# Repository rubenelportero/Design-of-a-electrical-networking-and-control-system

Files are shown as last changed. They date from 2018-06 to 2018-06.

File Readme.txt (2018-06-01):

Rubén García Segovia - 2018
https://github.com/rubenelportero

Este trabajo está bajo la licencia Creative Commons
de atribución y compartir igual 4.0. Todo el contenido
se encuentra bajo esta licencia, excepto las hojas
de características de los componentes electrónicos,
las cuales tienen sus licencias propietarias propias.
https://creativecommons.org/licenses/by-sa/4.0/legalcode

Además, todos los programas y códigos adjuntados en este proyecto 
son software libre: Puedes redistribuirlos o modificarlos
bajo los términos y condiciones de la licencia general de GNU
en su versión 3 o superior. 
http://www.gnu.org/licenses/

----------------------------------------------------------------------

This work is licensed under the Creative Commons
Attribution share-alike 4.0 license. All the content
is under this license, except for the included electronic
component data sheets, which have their own license. 
To view a copy of this license:
https://creativecommons.org/licenses/by-sa/4.0/legalcode

All programs/codes attached in this project are free software: 
you can redistribute them and/or modify them under the terms of 
the GNU General Public License as published by the Free Software 
Foundation, either version 3 of the License, or any later version.

All programs/codes are distributed in the hope that they will be useful,
but WITHOUT ANY WARRANTY; without even the implied warranty of
MERCHANTABILITY or FITNESS FOR A PARTICULAR PURPOSE.  See the
GNU General Public License for more details.

You should have received a copy of the GNU General Public License
along with this program.  If not, see <http://www.gnu.org/licenses/>.

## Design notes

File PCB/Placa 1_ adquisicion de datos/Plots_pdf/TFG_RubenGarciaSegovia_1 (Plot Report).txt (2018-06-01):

Plot Report
-----------

Report Written:     Monday, May 21, 2018
Project Path:       C:\Users\rubenelportero\Desktop\TFG\CD\PCB\Placa 1_ adquisicion de datos\TFG_RubenGarciaSegovia.prj
Design Path:        C:\Users\rubenelportero\Desktop\TFG\CD\PCB\Placa 1_ adquisicion de datos\TFG_RubenGarciaSegovia_1.pcb
Design Title:       
Created:            25/04/2018 18:19:07
Last Saved:         21/05/2018 18:58:55
Editing Time:       38 min
Units:              thou (precision 0)

Device Settings
===============

Gerber Settings
===============

    Leading zero suppression.
    G01 assumed throughout.
    Line termination <*> <CR> <LF>.
    3.5 format absolute inches.

    Format commands defined in Gerber file.
    Aperture table defined in Gerber file.
    Hardware arcs allowed.

Drill Settings
==============

    Excellon Format 1    Format 3.5 absolute in inches.
    Leading zero suppression.

Plots Output
============

Gerber Output
=============

C:\Users\rubenelportero\Desktop\TFG\CD\PCB\Placa 1_ adquisicion de datos\Plots_pdf\TFG_RubenGarciaSegovia_1 - Top Documentation.gbr

    Layers:
    ---------------------
    Top Documentation

    D-Code Shape  (thou)
    -----------------------
    D17    Round 5.00
    D18    Round 1.97

Gerber Output
=============

C:\Users\rubenelportero\Desktop\TFG\CD\PCB\Placa 1_ adquisicion de datos\Plots_pdf\TFG_RubenGarciaSegovia_1 - Top Silkscreen.gbr

    Layers:
    ------------------
    Top Silkscreen

    D-Code Shape  (thou)
    -----------------------
    D17    Round 5.00
    D19    Round 7.87

Gerber Output
=============

C:\Users\rubenelportero\Desktop\TFG\CD\PCB\Placa 1_ adquisicion de datos\Plots_pdf\TFG_RubenGarciaSegovia_1 - Top Copper.gbr

    Layers:
    --------------
    Top Copper

    D-Code Shape  (thou)
    ------------------------------------
    D71    Square 76.77
    D20    Round 76.77
    D23    Round 60.00
    D27    Round 15.00
    D28    Round 48.00
    D78    Square 64.96
    D79    Round 64.96
    D117   Rectangle 590.55 X 1102.36
    D118   Round 50.00

Gerber Output
=============

C:\Users\rubenelportero\Desktop\TFG\CD\PCB\Placa 1_ adquisicion de datos\Plots_pdf\TFG_RubenGarciaSegovia_1 - Top Solder Mask.gbr

    Layers:
    -------------------
    Top Solder Mask

    D-Code Shape  (thou)
    ------------------------------------
    D89    Round 66.00
    D90    Square 82.77
    D91    Round 82.77
    D94    Square 70.96
    D95    Round 70.96
    D103   Round 54.00
    D119   Rectangle 596.55 X 1108.36

Gerber Output
=============

C:\Users\rubenelportero\Desktop\TFG\CD\PCB\Placa 1_ adquisicion de datos\Plots_pdf\TFG_RubenGarciaSegovia_1 - Top Paste Mask.gbr

    Layers:
    ------------------
    Top Paste Mask

    D-Code Shape  (thou)
    ------------------------------------
    D120   Rectangle 584.55 X 1096.36

Gerber Output
=============

C:\Users\rubenelportero\Desktop\TFG\CD\PCB\Placa 1_ adquisicion de datos\Plots_pdf\TFG_RubenGarciaSegovia_1 - Bottom Copper.gbr

    Layers:
    -----------------
    Bottom Copper

    D-Code Shape  (thou)
    -----------------------
    D16    Round 100.00
    D71    Square 76.77
    D20    Round 76.77
    D23    Round 60.00
    D27    Round 15.00
    D28    Round 48.00
    D78    Square 64.96
    D79    Round 64.96
    D118   Round 50.00
    D121   Round 25.00
    D122   Round 35.00

Gerber Output
=============

C:\Users\rubenelportero\Desktop\TFG\CD\PCB\Placa 1_ adquisicion de datos\Plots_pdf\TFG_RubenGarciaSegovia_1 - Bottom Copper (Resist).gbr

    Layers:
    -----------------
    Bottom Copper

    D-Code Shape  (thou)
    -----------------------
    D10    Square 86.77
    D11    Round 86.77
    D12    Round 70.00
    D112   Square 74.96
    D113   Round 74.96

Gerber Output
=============

C:\Users\rubenelportero\Desktop\TFG\CD\PCB\Placa 1_ adquisicion de datos\Plots_pdf\TFG_RubenGarciaSegovia_1 - Bottom Copper (Paste).gbr

    Layers:
    -----------------
    Bottom Copper

    D-Code Shape  (thou)
    -----------------------

NC Drill Output
===============

C:\Users\rubenelportero\Desktop\TFG\CD\PCB\Placa 1_ adquisicion de datos\Plots_pdf\TFG_RubenGarciaSegovia_1 - Drill Data - [Through Hole].drl

    Output:
    ---------------------------
    Plated Round Drill Holes
    Plated Slots
    Plated Board Outlines

    Tool  Size           Count   ID
    --------------------------------------
    T001  0.02400 inches 17    D
    T002  0.03200 inches 32    A
    T003  0.04331 inches 20    B
    T004  0.05118 inches 12    C
    --------------------------------------
    Total                81
    --------------------------------------

C:\Users\rubenelportero\Desktop\TFG\CD\PCB\Placa 1_ adquisicion de datos\Plots_pdf\TFG_RubenGarciaSegovia_1 - Drill Data - [Through Hole] (Unplated).drl

    Output:
    -----------------------------
    Unplated Round Drill Holes
    Unplated Slots
    Unplated Board Outlines

    Tool  Size           Count   ID
    --------------------------------------
    T001  0.02500 inches 1
    --------------------------------------
    Total                1
    --------------------------------------

Gerber Output
=============

C:\Users\rubenelportero\Desktop\TFG\CD\PCB\Placa 1_ adquisicion de datos\Plots_pdf\TFG_RubenGarciaSegovia_1 - Drill Ident Drawing - [Through Hole].gbr

    Layers:
    ------------------
    [Through Hole]

Drill Ident Drawing
===================

    Drill Plated Size Shape ID
    -----------------------------------
    32    Y      100  Round A
    43    Y      100  Round B
    51    Y      100  Round C
    24    Y      100  Round D

    D-Code Shape  (thou)
    -----------------------
    D16    Round 100.00
    D17    Round 5.00

End Of Report.

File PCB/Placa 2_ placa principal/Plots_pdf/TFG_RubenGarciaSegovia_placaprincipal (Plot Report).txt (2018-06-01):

Plot Report
-----------

Report Written:     Monday, May 21, 2018
Project Path:       C:\Users\rubenelportero\Desktop\TFG\CD\PCB\Placa 2_ placa principal\TFG_RubenGarciaSegovia_placaprincipal.prj
Design Path:        C:\Users\rubenelportero\Desktop\TFG\CD\PCB\Placa 2_ placa principal\TFG_RubenGarciaSegovia_placaprincipal.pcb
Design Title:       
Created:            14/05/2018 12:30:43
Last Saved:         21/05/2018 18:56:52
Editing Time:       201 min
Units:              thou (precision 0)

Device Settings
===============

Gerber Settings
===============

    Leading zero suppression.
    G01 assumed throughout.
    Line termination <*> <CR> <LF>.
    3.5 format absolute inches.

    Format commands defined in Gerber file.
    Aperture table defined in Gerber file.
    Hardware arcs allowed.

Drill Settings
==============

    Excellon Format 1    Format 3.5 absolute in inches.
    Leading zero suppression.

Plots Output
============

Gerber Output
=============

C:\Users\rubenelportero\Desktop\TFG\CD\PCB\Placa 2_ placa principal\Plots_pdf\TFG_RubenGarciaSegovia_placaprincipal - Top Documentation.gbr

    Layers:
    ---------------------
    Top Documentation

    D-Code Shape  (thou)
    -----------------------
    D18    Round 1.97

Gerber Output
=============

C:\Users\rubenelportero\Desktop\TFG\CD\PCB\Placa 2_ placa principal\Plots_pdf\TFG_RubenGarciaSegovia_placaprincipal - Top Silkscreen.gbr

    Layers:
    ------------------
    Top Silkscreen

    D-Code Shape  (thou)
    -----------------------
    D17    Round 5.00
    D19    Round 7.87
    D70    Round 10.00
    D73    Round 6.00

Gerber Output
=============

C:\Users\rubenelportero\Desktop\TFG\CD\PCB\Placa 2_ placa principal\Plots_pdf\TFG_RubenGarciaSegovia_placaprincipal - Top Copper.gbr

    Layers:
    --------------
    Top Copper

    D-Code Shape  (thou)
    ----------------------------------------------
    D17    Round 5.00
    D70    Round 10.00
    D71    Square 76.77
    D20    Round 76.77
    D22    Rectangle 55.00 X 60.00
    D23    Round 60.00
    D27    Round 15.00
    D28    Round 48.00
    D74    Rectangle 11.00 X 58.00  Rotation 90
    D75    Rectangle 11.00 X 58.00
    D76    Square 47.24
    D77    Round 47.24
    D78    Square 64.96
    D79    Round 64.96
    D80    Square 46.61
    D81    Round 46.61
    D82    Rectangle 25.59 X 70.87
    D83    Round 44.49
    D84    Rectangle 55.00 X 60.00  Rotation 90
    D85    Rectangle 19.69 X 29.53  Rotation 90
    D86    Round 56.00

Gerber Output
=============

C:\Users\rubenelportero\Desktop\TFG\CD\PCB\Placa 2_ placa principal\Plots_pdf\TFG_RubenGarciaSegovia_placaprincipal - Top Solder Mask.gbr

    Layers:
    -------------------
    Top Solder Mask

    D-Code Shape  (thou)
    ----------------------------------------------
    D87    Rectangle 17.00 X 64.00  Rotation 90
    D88    Rectangle 17.00 X 64.00
    D89    Round 66.00
    D90    Square 82.77
    D91    Round 82.77
    D92    Square 53.24
    D93    Round 53.24
    D94    Square 70.96
    D95    Round 70.96
    D96    Square 52.61
    D97    Round 52.61
    D98    Rectangle 31.59 X 76.87
    D99    Round 50.49
    D100   Rectangle 61.00 X 66.00  Rotation 90
    D101   Rectangle 61.00 X 66.00
    D102   Rectangle 25.69 X 35.53  Rotation 90
    D103   Round 54.00
    D104   Round 62.00

Gerber Output
=============

C:\Users\rubenelportero\Desktop\TFG\CD\PCB\Placa 2_ placa principal\Plots_pdf\TFG_RubenGarciaSegovia_placaprincipal - Top Paste Mask.gbr

    Layers:
    ------------------
    Top Paste Mask

    D-Code Shape  (thou)
    ----------------------------------------------
    D72    Rectangle 49.00 X 54.00
    D105   Rectangle 5.00 X 52.00  Rotation 90
    D106   Rectangle 5.00 X 52.00
    D107   Rectangle 19.59 X 64.87
    D108   Rectangle 49.00 X 54.00  Rotation 90
    D109   Rectangle 13.69 X 23.53  Rotation 90

Gerber Output
=============

C:\Users\rubenelportero\Desktop\TFG\CD\PCB\Placa 2_ placa principal\Plots_pdf\TFG_RubenGarciaSegovia_placaprincipal - Bottom Copper.gbr

    Layers:
    -----------------
    Bottom Copper

    D-Code Shape  (thou)
    -----------------------
    D17    Round 5.00
    D70    Round 10.00
    D71    Square 76.77
    D20    Round 76.77
    D23    Round 60.00
    D27    Round 15.00
    D28    Round 48.00
    D76    Square 47.24
    D77    Round 47.24
    D78    Square 64.96
    D79    Round 64.96
    D80    Square 46.61
    D81    Round 46.61
    D83    Round 44.49
    D86    Round 56.00

Gerber Output
=============

C:\Users\rubenelportero\Desktop\TFG\CD\PCB\Placa 2_ placa principal\Plots_pdf\TFG_RubenGarciaSegovia_placaprincipal - Bottom Copper (Resist).gbr

    Layers:
    -----------------
    Bottom Copper

    D-Code Shape  (thou)
    -----------------------
    D10    Square 86.77
    D11    Round 86.77
    D12    Round 70.00
    D110   Square 57.24
    D111   Round 57.24
    D112   Square 74.96
    D113   Round 74.96
    D114   Square 56.61
    D115   Round 56.61
    D116   Round 54.49

Gerber Output
=============

C:\Users\rubenelportero\Desktop\TFG\CD\PCB\Placa 2_ placa principal\Plots_pdf\TFG_RubenGarciaSegovia_placaprincipal - Bottom Copper (Paste).gbr

    Layers:
    -----------------
    Bottom Copper

    D-Code Shape  (thou)
    -----------------------

NC Drill Output
===============

C:\Users\rubenelportero\Desktop\TFG\CD\PCB\Placa 2_ placa principal\Plots_pdf\TFG_RubenGarciaSegovia_placaprincipal - Drill Data - [Through Hole].drl

    Output:
    ---------------------------
    Plated Round Drill Holes
    Plated Slots
    Plated Board Outlines

    Tool  Size           Count   ID
    --------------------------------------
    T001  0.02400 inches 106   G
    T002  0.02480 inches 4     F
    T003  0.03087 inches 14    E
    T004  0.03150 inches 28    C
    T005  0.03200 inches 49    A
    T006  0.04331 inches 36    D
    T007  0.05118 inches 4     B
    --------------------------------------
    Total                241
    --------------------------------------

C:\Users\rubenelportero\Desktop\TFG\CD\PCB\Placa 2_ placa principal\Plots_pdf\TFG_RubenGarciaSegovia_placaprincipal - Drill Data - [Through Hole] (Unplated).drl

    Output:
    -----------------------------
    Unplated Round Drill Holes
    Unplated Slots
    Unplated Board Outlines

    Tool  Size           Count   ID
    --------------------------------------
    T001  0.02500 inches 1
    --------------------------------------
    Total                1
    --------------------------------------

Gerber Output
=============

C:\Users\rubenelportero\Desktop\TFG\CD\PCB\Placa 2_ placa principal\Plots_pdf\TFG_RubenGarciaSegovia_placaprincipal - Drill Ident Drawing - [Through Hole].gbr

    Layers:
    ------------------
    [Through Hole]

Drill Ident Drawing
===================

    Drill Plated Size Shape ID
    -----------------------------------
    32    Y      100  Round A
    51    Y      100  Round B
    31    Y      100  Round C
    43    Y      100  Round D
    31    Y      100  Round E
    25    Y      100  Round F
    24    Y      100  Round G

    D-Code Shape  (thou)
    -----------------------
    D16    Round 100.00
    D17    Round 5.00

End Of Report.

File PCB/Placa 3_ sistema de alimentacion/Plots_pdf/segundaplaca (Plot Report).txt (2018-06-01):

Plot Report
-----------

Report Written:     Monday, May 21, 2018
Project Path:       C:\Users\rubenelportero\Desktop\TFG\CD\PCB\Placa 3_ sistema de alimentacion\segundaplaca.prj
Design Path:        C:\Users\rubenelportero\Desktop\TFG\CD\PCB\Placa 3_ sistema de alimentacion\segundaplaca.pcb
Design Title:       
Created:            30/04/2018 19:52:52
Last Saved:         02/05/2018 17:16:53
Editing Time:       29 min
Units:              thou (precision 0)

Device Settings
===============

Gerber Settings
===============

    Leading zero suppression.
    G01 assumed throughout.
    Line termination <*> <CR> <LF>.
    3.5 format absolute inches.

    Format commands defined in Gerber file.
    Aperture table defined in Gerber file.
    Hardware arcs allowed.

Drill Settings
==============

    Excellon Format 1    Format 3.5 absolute in inches.
    Leading zero suppression.

Plots Output
============

Gerber Output
=============

C:\Users\rubenelportero\Desktop\TFG\CD\PCB\Placa 3_ sistema de alimentacion\Plots_pdf\segundaplaca - Top Documentation.gbr

    Layers:
    ---------------------
    Top Documentation

    D-Code Shape  (thou)
    -----------------------
    D18    Round 1.97

Gerber Output
=============

C:\Users\rubenelportero\Desktop\TFG\CD\PCB\Placa 3_ sistema de alimentacion\Plots_pdf\segundaplaca - Top Silkscreen.gbr

    Layers:
    ------------------
    Top Silkscreen

    D-Code Shape  (thou)
    -----------------------
    D17    Round 5.00
    D19    Round 7.87
    D70    Round 10.00

Gerber Output
=============

C:\Users\rubenelportero\Desktop\TFG\CD\PCB\Placa 3_ sistema de alimentacion\Plots_pdf\segundaplaca - Top Copper.gbr

    Layers:
    --------------
    Top Copper

    D-Code Shape  (thou)
    ----------------------------------------------
    D71    Square 76.77
    D20    Round 76.77
    D21    Rectangle 62.99 X 88.58
    D22    Rectangle 55.00 X 60.00
    D23    Round 60.00
    D24    Square 80.91
    D25    Round 80.91
    D26    Rectangle 60.00 X 80.00  Rotation 90
    D27    Round 15.00
    D28    Round 48.00

Gerber Output
=============

C:\Users\rubenelportero\Desktop\TFG\CD\PCB\Placa 3_ sistema de alimentacion\Plots_pdf\segundaplaca - Top Solder Mask.gbr

    Layers:
    -------------------
    Top Solder Mask

    D-Code Shape  (thou)
    ----------------------------------------------
    D89    Round 66.00
    D90    Square 82.77
    D91    Round 82.77
    D101   Rectangle 61.00 X 66.00
    D123   Rectangle 68.99 X 94.58
    D124   Square 86.91
    D125   Round 86.91
    D126   Rectangle 66.00 X 86.00  Rotation 90

Gerber Output
=============

C:\Users\rubenelportero\Desktop\TFG\CD\PCB\Placa 3_ sistema de alimentacion\Plots_pdf\segundaplaca - Top Paste Mask.gbr

    Layers:
    ------------------
    Top Paste Mask

    D-Code Shape  (thou)
    ---------------------------------
    D29    Rectangle 56.99 X 82.58
    D72    Rectangle 49.00 X 54.00

Gerber Output
=============

C:\Users\rubenelportero\Desktop\TFG\CD\PCB\Placa 3_ sistema de alimentacion\Plots_pdf\segundaplaca - Bottom Copper.gbr

    Layers:
    -----------------
    Bottom Copper

    D-Code Shape  (thou)
    ----------------------------------------------
    D71    Square 76.77
    D20    Round 76.77
    D23    Round 60.00
    D24    Square 80.91
    D25    Round 80.91
    D26    Rectangle 60.00 X 80.00  Rotation 90
    D27    Round 15.00
    D28    Round 48.00

Gerber Output
=============

C:\Users\rubenelportero\Desktop\TFG\CD\PCB\Placa 3_ sistema de alimentacion\Plots_pdf\segundaplaca - Bottom Copper (Resist).gbr

    Layers:
    -----------------
    Bottom Copper

    D-Code Shape  (thou)
    ----------------------------------------------
    D10    Square 86.77
    D11    Round 86.77
    D12    Round 70.00
    D13    Square 90.91
    D14    Round 90.91
    D15    Rectangle 70.00 X 90.00  Rotation 90

Gerber Output
=============

C:\Users\rubenelportero\Desktop\TFG\CD\PCB\Placa 3_ sistema de alimentacion\Plots_pdf\segundaplaca - Bottom Copper (Paste).gbr

    Layers:
    -----------------
    Bottom Copper

    D-Code Shape  (thou)
    -----------------------

NC Drill Output
===============

C:\Users\rubenelportero\Desktop\TFG\CD\PCB\Placa 3_ sistema de alimentacion\Plots_pdf\segundaplaca - Drill Data - [Through Hole].drl

    Output:
    ---------------------------
    Plated Round Drill Holes
    Plated Slots
    Plated Board Outlines

    Tool  Size           Count   ID
    --------------------------------------
    T001  0.02400 inches 4     E
    T002  0.03000 inches 4     D
    T003  0.03200 inches 31    B
    T004  0.05118 inches 8     A
    T005  0.05394 inches 9     C
    --------------------------------------
    Total                56
    --------------------------------------

C:\Users\rubenelportero\Desktop\TFG\CD\PCB\Placa 3_ sistema de alimentacion\Plots_pdf\segundaplaca - Drill Data - [Through Hole] (Unplated).drl

    Output:
    -----------------------------
    Unplated Round Drill Holes
    Unplated Slots
    Unplated Board Outlines

    Tool  Size           Count   ID
    --------------------------------------
    T001  0.02500 inches 1
    --------------------------------------
    Total                1
    --------------------------------------

Gerber Output
=============

C:\Users\rubenelportero\Desktop\TFG\CD\PCB\Placa 3_ sistema de alimentacion\Plots_pdf\segundaplaca - Drill Ident Drawing - [Through Hole].gbr

    Layers:
    ------------------
    [Through Hole]

Drill Ident Drawing
===================

    Drill Plated Size Shape ID
    -----------------------------------
    51    Y      100  Round A
    32    Y      100  Round B
    54    Y      100  Round C
    30    Y      100  Round D
    24    Y      100  Round E

    D-Code Shape  (thou)
    -----------------------
    D16    Round 100.00
    D17    Round 5.00

End Of Report.

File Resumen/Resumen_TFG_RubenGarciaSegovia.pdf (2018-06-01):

## UNIVERSIDAD DE CASTILLA-LA MANCHA

### ESCUELA DE INGENIEROS INDUSTRIALES DE ALBACETE

### GRADUADO EN INGENIERÍA EN ELECTRÓNICA IND. Y AUTOMÁTICA

### TRABAJO FIN DE GRADO

## DISEÑO DE UN DISPOSITIVO DE MONITORIZACIÓN DE REDES ELÉCTRICAS EN EL ENTORNO DEL INTERNET INDUSTRIAL DE LAS COSAS (IIOT)

### Nº DE TFG: 01EN1796/17Xl

### AUTOR: Rubén García Segovia

### TUTOR: Miguel Martínez Iniesta

### Junio, 2018

En estos agradecimientos y dedicatorias quiero nombrar a varias personas,

Los primeros serán mis compañeros de carrera,

Por todo el tiempo pasado juntos, sin vosotros no habría sido posible.

La segunda dedicatoria va para mi madre,

Por todas aquellas veces que me dijo que estudiase,

y sin embargo, nunca le hice caso,

¡Qué razón llevaba!

Por último quiero agradecerle a ese chaval de 18 años que escogió formarse como ingeniero, ¡Menudos años me has hecho pasar!

TRABAJO FIN DE GRADO Nº 01EN1796/17Xl | ÍNDICE

# ÍNDICE GENERAL

TRABAJO FIN DE GRADO Nº 01EN1796/17Xl | ÍNDICE

TRABAJO FIN DE GRADO Nº 01EN1796/17Xl | ÍINTRODUCCIÓN

# INTRODUCCIÓN

El objetivo general del TFG será la realización, diseño y prototipado de un dispositivo capaz de medir y calcular diversos parámetros de la red eléctrica de una industria y almacenar dicha información en una base de datos.

La base de datos será accesible a través de internet, contando con una interfaz de usuario funcional y que permita la visualización y ordenación de toda la información recogida por el dispositivo central.

También será accesible a través de una pantalla táctil, contando con una interfaz gráfica funcional y que permita la visualización y actuación sobre todo el sistema de una forma sencilla e intuitiva.

Por último, se va a desarrollar una aplicación móvil para el entorno Android para facilitar un acceso más rápido a la información, aunque dicha aplicación sólo permitirá la visualización limitada (los datos más importantes) de la información.

Con esto se pretende crear una herramienta que facilite a una empresa el control energético, el análisis de la red en busca de fallos o problemas en el suministro eléctrico, y encontrar fallos de rendimiento y/o funcionamiento en sus propias máquinas.

El objetivo general se va a dividir en diferentes objetivos parciales que se irán detallando a lo largo del desarrollo del TFG:

- Medición de voltajes e intensidades en una red eléctrica industrial, aislando el circuito de control de la toma de fuerza. La comunicación mediante el protocolo serie SPI de los distintos sensores con la unidad principal.
- Cálculo de parámetros básicos en base a las lecturas de voltajes e intensidades realizados: Potencia activa, potencia aparente, potencia reactiva, factor de potencia, etc.
- Almacenamiento de toda la información en una base de datos localizada en un computador de placa reducida. Comunicación entre el computador de placa reducida y la unidad principal para la obtención de toda la información obtenida y calculada.
- Creación de una interfaz de usuario que permita acceder a toda la información almacenada en la base de datos a través de un servidor web.
- Creación de una interfaz gráfica que permite acceder a toda la información almacenada en la base de datos a través de una pantalla táctil.
- Creación de una aplicación móvil que permita visualizar de forma simple la información más importante.

TRABAJO FIN DE GRADO Nº 01EN1796/17Xl | DESCRIPCIÓN

# DESCRIPCIÓN

Primero se va a exponer y explicar qué es la calidad de la energía y el porqué de su importancia en la industria.

Calidad de la energía

La calidad de la energía es un factor muy importante a tener en cuenta en una industria, debido a que el deterioro, la avería o los problemas que son dados en las máquinas de la empresa están directamente relacionados con la calidad de la energía consumida. A continuación se exponen dos definiciones de calidad de energía según dos grandes organismos internaciones de ingeniería:

Según el IEEE (Institute of Electrical and Electronic Engineers), la calidad de la energía es la alimentación y puesta a tierra de los equipos electrónicos sensibles de un modo adecuado para su correcto funcionamiento.

Según el IEC (International Electrotechnical Commision) son las características de la electricidad en un punto dado de la red eléctrica, evaluadas con relación a un conjunto de parámetros técnicos de referencia.

El principal problema de la calidad de la energía es solventable a través de dos soluciones: construcción de máquinas menos sensibles y la instalación de dispositivos a medida que se encarguen de subsanar la mala calidad de la energía.

El concepto de calidad de energía no es nuevo, pero debido a la tendencia de la industria hacia usar semiconductores de potencia no lineales (como inversores, convertidores, tiristores, etc) y el aumento de la sensibilidad de los equipos finales han obligado a la industria a diseñar dispositivos específicos para mejorar este aspecto de la electricidad.

Prueba de que la preocupación por la calidad de la energía va en aumento es la creación de nuevas normas AENOR sobre las especificaciones de la tensión.

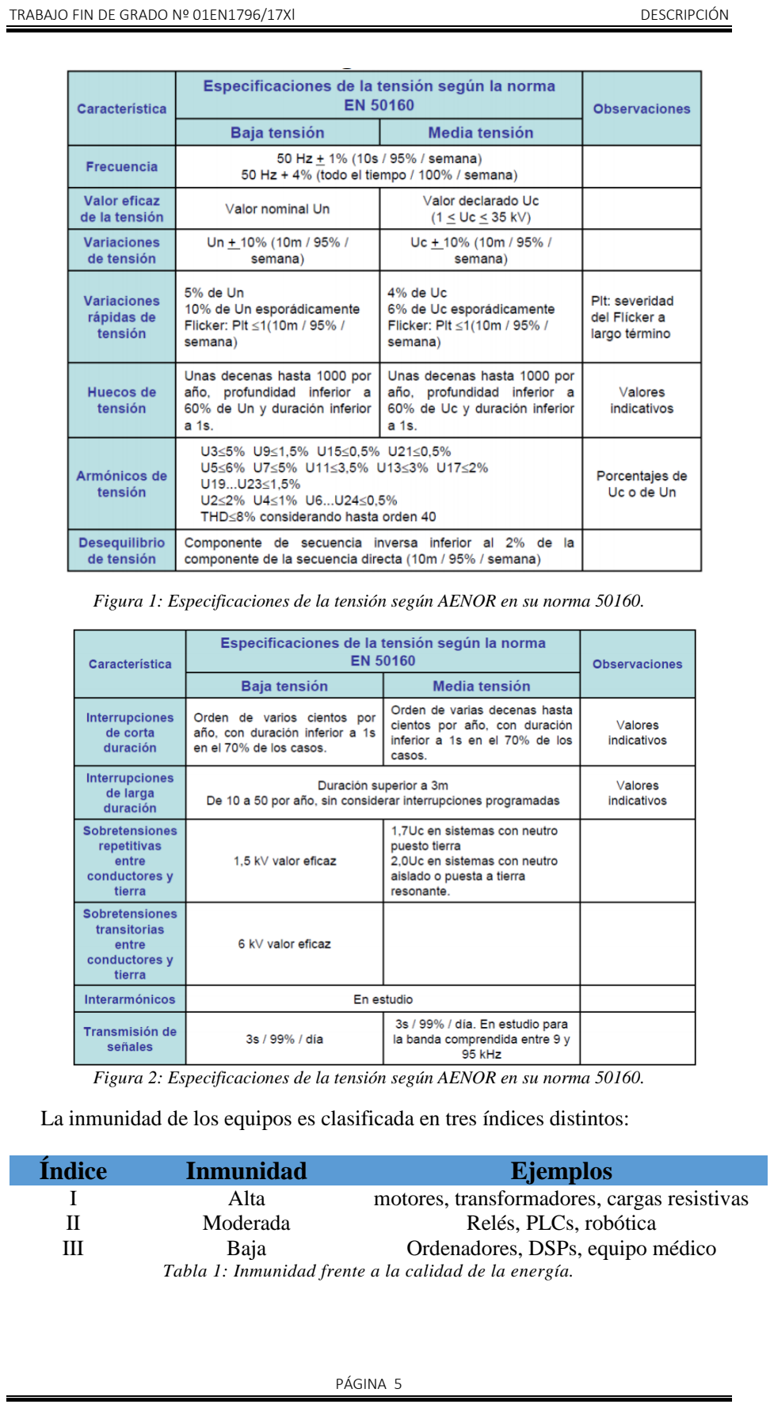
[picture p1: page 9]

TRABAJO FIN DE GRADO Nº 01EN1796/17Xl | DESCRIPCIÓN

Figura 1: Especificaciones de la tensión según AENOR en su norma 50160.

Figura 2: Especificaciones de la tensión según AENOR en su norma 50160.

La inmunidad de los equipos es clasificada en tres índices distintos:

Índice | Inmunidad | Ejemplos
I | Alta | motores, transformadores, cargas resistivas
II | Moderada | Relés, PLCs, robótica
III | Baja | Ordenadores, DSPs, equipo médico
Tabla 1: Inmunidad frente a la calidad de la energía.

TRABAJO FIN DE GRADO Nº 01EN1796/17Xl | DESCRIPCIÓN

Diagrama de bloques del dispositivo
Antes de comenzar con la división estructural del proyecto en diferentes apartados o capítulos se ha realizado un diagrama de bloques para explicar de una forma más clara y sencilla el conjunto del dispositivo:

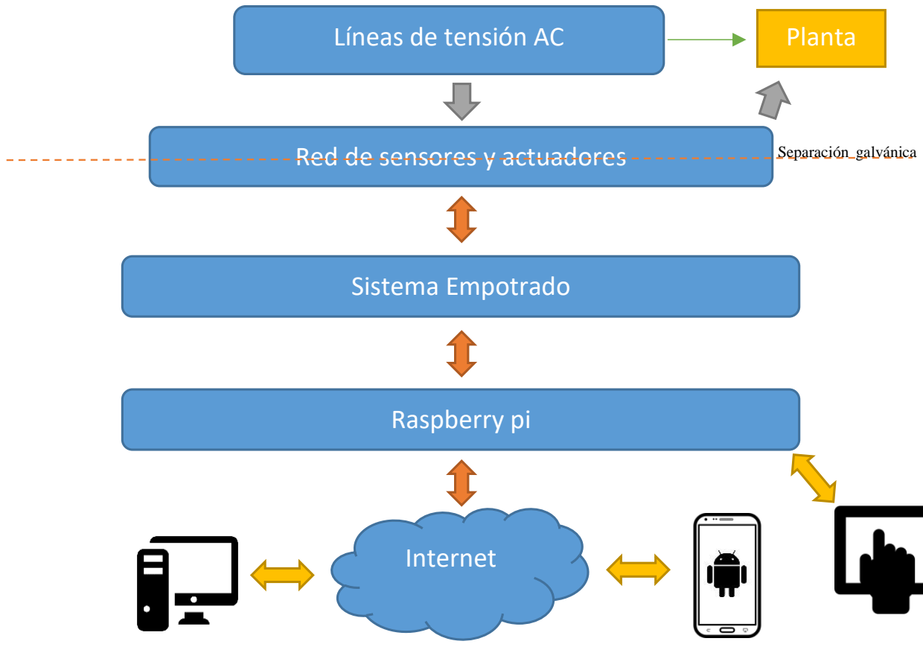
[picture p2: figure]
Separación galvánica; Líneas de tensión AC; Red de sensores y actuadores; Planta; Sistema Empotrado; Raspberry pi; Internet

Figura 3: Diagrama de bloques del sistema completo.

El trabajo se ha estructurado en diferentes apartados o capítulos en los que se ha dividido el desarrollo del TFG para una mejor aclaración y entendimiento del sistema.

Medición de parámetros de red

La medición del voltaje de cada una de las tres líneas de fase con respecto a tierra y el voltaje de la línea neutra con respecto a la línea de tierra. También se va a medir las 4 intensidades circulantes por cada una de estas 4 líneas comentadas, así como la temperatura ambiente del cuadro eléctrico.

Todas estas mediciones se van a realizar en un circuito diferente al de control y se contará con un aislamiento galvánico para evitar fallos o problemas ocasionados por sobretensiones o fluctuaciones en la red.

Comunicación mediante el protocolo SPI

La transmisión de los parámetros de red y la unidad principal se harán a través del protocolo SPI, por lo que dicho protocolo será objeto de estudio.

TRABAJO FIN DE GRADO Nº 01EN1796/17Xl | DESCRIPCIÓN

Cálculo de parámetros de red

El post-procesado de los parámetros de red voltaje, intensidad y temperatura se realizará en el computador de placa reducida aprovechando su amplia capacidad de cálculo. Una vez que se tengan calculados dichos parámetros, se podrá realizar un cálculo más complejo de los siguientes parámetros:

- Factor de potencia: El factor de potencia es la relación existente entre la potencia activa del circuito y la potencia aparente. Es un parámetro de gran importancia a la hora de analizar si nuestra carga funciona
correctamente. | Además, | las | compañías | comercializadoras | de
electricidad penalizan duramente el consumo eléctrico con un factor de potencia bajo.
- Potencia aparente, activa y reactiva: La potencia aparente es resultado de la suma vectorial de la potencia activa y reactiva y por tanto es el mejor indicador de potencia total consumida por una instalación eléctrica.

La potencia activa es aquella potencia eléctrica que se transforma en calor o trabajo, por lo que es el mejor indicador para designar el trabajo realizado por una máquina.

Por último, la potencia reactiva es aquella potencia consumida mediante la generación de campos eléctricos y magnéticos, necesarios para el correcto funcionamiento de muchas máquinas.

- Desequilibrios entre las fases: Mediante la comparación de intensidades y voltajes se puede averiguar si existen desequilibrios de carga entre las fases, lo que generará desestabilidad a la red eléctrica y generación de armónicos indeseados.
- Huecos de tensión: Disminución brusca de tensión a un valor de entre el 90% y el 1% de la tensión nominal por un período de tiempo comprendido entre 1ms y 1 minuto. Si la duración es mayor se considera interrupción.
- Sobretensiones: Aumento brusco de la tensión a un valor de entre el 10% y el 80% que duración usual de unos pocos ciclos.
- Espectro frecuencial: La realización de una transformada de Fourier para el análisis del espectro frecuencial de la señal permite encontrar armónicos no deseados en la red. Dichos armónicos pueden hacer que nuestras máquinas se sobrecalienten, disminuyan su vida útil, funcionen erróneamente y hasta la avería de las mismas en el peor de los casos.

TRABAJO FIN DE GRADO Nº 01EN1796/17Xl | DESCRIPCIÓN
- THD: La distorsión armónica total es una unidad de medida de componentes armónicos en nuestra red eléctrica.
- Consumo eléctrico: Aparte del cálculo de las potencias instantáneas, también es de interés el almacenar información sobre el consumo eléctrico por minutos, horas, días, meses y años.

Almacenamiento de la información

La información recolectada sobre todos los parámetros leídos y calculados se organizarán de forma correcta en una base de datos dentro del computador de placa reducida.

Servidor Web

Toda la base de datos tiene que ser accesible mediante un servidor web que contará con una interfaz de usuario simple que permita organizar y mostrar toda la información de forma clara y concisa. Este servidor web ha de ser accesible desde cualquier dispositivo con conexión a Internet.

Aplicación móvil

Se contará con una aplicación para la plataforma Android que facilitará la conexión con el servidor y base de datos a través de un teléfono móvil o Tablet. Desde esta aplicación será visible la información y los parámetros de red más importantes.

Pantalla táctil

Se contará con una pantalla táctil de siete pulgadas para la visualización de los parámetros más importantes del servidor. Desde la pantalla táctil se podrá actuar sobre los actuadores y el sistema en general.

FTP

Se ha implementado el protocolo FTP (File Transfer Protocol) para poder acceder a todos los datos guardados dentro del servidor. También se podrá actualizar el software del sistema a través de él.

Sistema de alimentación ininterrumpida

El dispositivo contará con un sistema de alimentación ininterrumpida de modo que si la alimentación de entrada se interrumpe, el sistema pueda funcionar con una batería y por tanto sea capaz de alertar del problema.

TRABAJO FIN DE GRADO Nº 01EN1796/17Xl | DESARROLLO

# DESARROLLO

### 1. Monitorización red eléctrica trifásica

### 1.1 Conversor analógico digital ADE7912

Las características que se requieren del conversor analógico digital son las siguientes:
- Alta resolución para efectuar cálculos precisos, como la FFT (Fast Fourier Transform).
- Capacidad para medir distintos parámetros a la vez o capacidad de coexistir con otros conversores analógico digitales en paralelo.
- Interfaz de comunicación veloz y simple.
- Frecuencia de muestreo mayor que 1000Hz.
- Separación galvánica entre la entrada analógica y la salida digital.

El conversor seleccionado es el ADE7912 y el ADE7913 que se ajustan perfectamente a las necesidades del sistema, ya que se trata de un conversor específico para la monitorización trifásica y el control de la calidad de energía. Según el fabricante, este conversor está especialmente indicado para:

- Equipos de medida polifásicos.
- Monitorización de la calidad de la energía.
- Inversores solares.
- PLCs industriales.
- Interfaz de sensores con aislamiento galvánico.

Debido a que el conversor ADE7912/ADE7913 está específicamente desarrollado para la monitorización de una red eléctrica, ofrece la capacidad de medir los valores de tensión, intensidad y temperatura ambiente al mismo tiempo, con una precisión de 24 bits y una tasa de muestreo de hasta 8000Hz.

Permite sincronización automática entre 4 ADE diferentes y el funcionando con el mismo cristal. Posee un protocolo de comunicación SPI con una separación galvánica entre la entrada analógica y la salida digital que facilita el uso de un microcontrontrolador para el sistema empotrado.

La única diferencia entre la versión 7912 y la versión 7913 radica en que la versión ADE7912 cuenta únicamente con 2 ADCs más la medición de temperatura y la versión 7913 cuenta con 3 ADCs. Como sólo se van a utilizar para la monitorización de voltaje, intensidad y temperatura, se usarán 4 ADE7912.

Tal y como se muestra en la figura 4, el propio fabricante propone un esquema de conexionado:

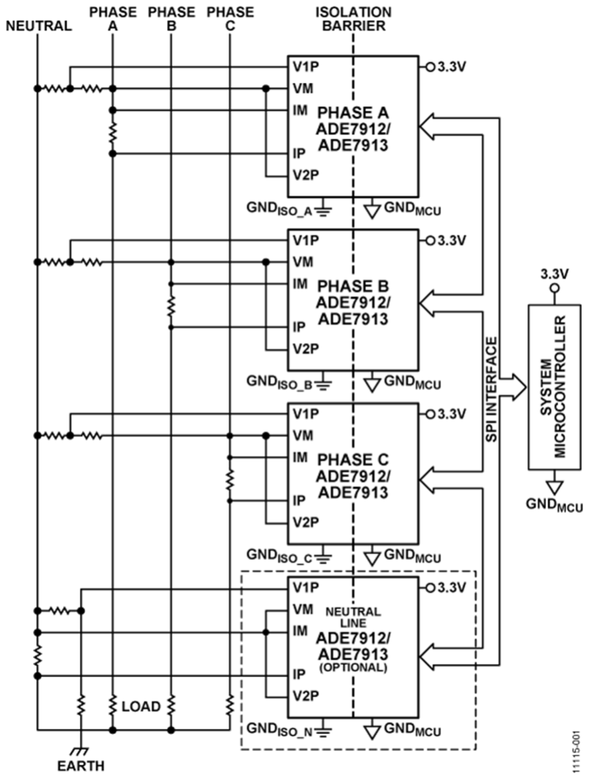
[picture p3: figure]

Figura 4: Esquema modelo del ADE7912/ADE7913.

Como se puede apreciar en la figura 4, este esquema modelo permite, mediante el uso de 4 conversores ADE, medir los voltajes entre cada una de las 3 fases con neutro y el voltaje de la línea neutro respecto a la línea de tierra (un parámetro importante a la hora de detectar desequilibrios) además de permitir la monitorización de las 4 corrientes circulantes y además, de necesitarse, la temperatura ambiente de los cables.

### 1.2 Medición voltaje

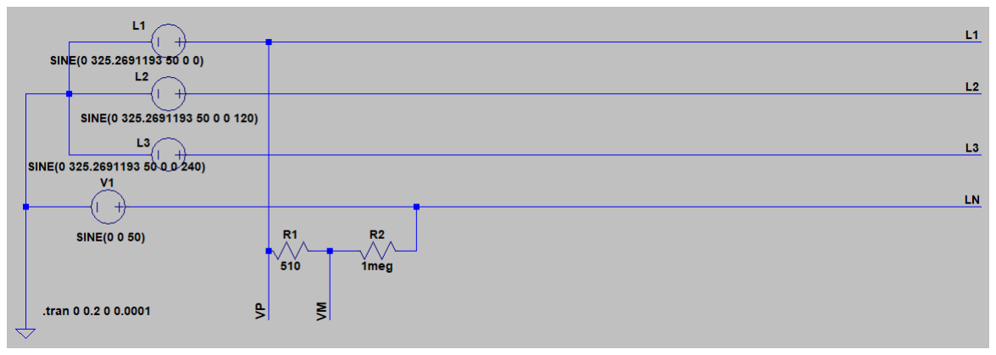
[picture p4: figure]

Figura 5: Circuito trifásico a monitorizar. Voltaje.

En la figura 5 se puede observar los valores escogidos de las resistencias para hacer el divisor de tensión. Para llegar a este cálculo hemos seguido los siguientes pasos:
Primero: Fijamos R2 en 1MΩ. Se ha elegido un valor de resistencia muy alta para evitar la pérdida de energía en la medida.

I =

V
R

; i =

1000
10⁶ + R

(1)

V = I ∗ R; 0.5V =

1000
10⁶ + R

∗ R (2)

Operando con las ecuaciones (1) y (2) se saca un valor de R=500.25Ω. Como es un valor no normalizado, se ha tomado R=510 Ω y se realiza un estudio para averiguar hasta qué voltaje podrá ser capaz el sistema de medir:

0.5V =

X
10⁶ + 510 ∗ 510; X = 980.8921V (3)

Teniendo en cuenta que no se han operado con valores eficaces, realizamos la última transformación:
Vrms:

980.8921
√2

= 693.5954V (4)

Para comprobar todos estos cálculos, se ha realizado una simulación con una onda senoidal de amplitud 980.89V, obteniendo la siguiente respuesta:

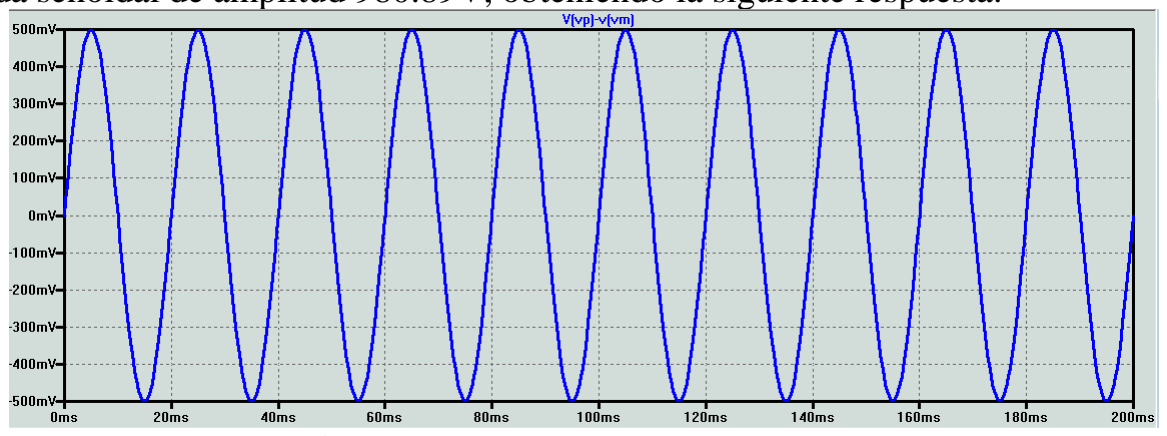
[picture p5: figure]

Figura 6: señal de voltaje condicionada para su medida.

### 1.3 Medición intensidad

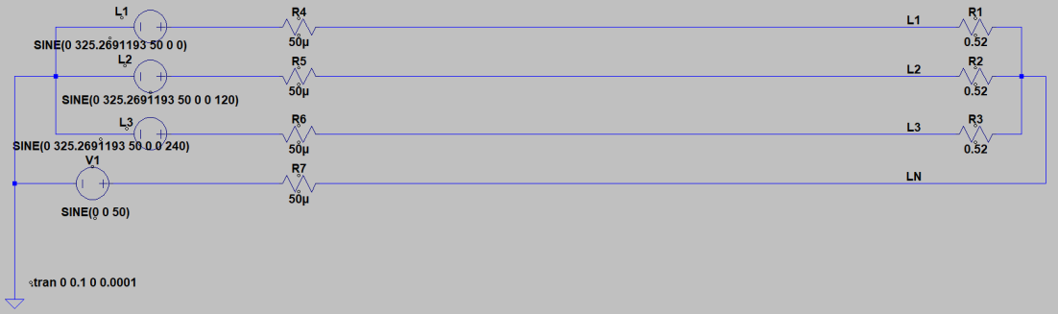
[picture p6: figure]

Figura 7: Circuito trifásico a monitorizar. Intensidad.

En la figura 7 se pueden observar los valores escogidos de la resistencia para realizar la medición de la intensidad circulante por la fase L1. De forma análoga, todas las demás líneas tendrán la misma resistencia para mantener el equilibrio de la red. Para llegar a este cálculo hemos seguido los siguientes pasos:

Primero se han de buscar los valores normalizados de las resistencias shunt. Para esto se ha realizado un seguimiento de mercado en los proveedores más reconocidos hasta encontrar la resistencia ‘WSBS8518L0500JK40’ de Vishay, cuyas características se encuentran en el anexo 1.

Una vez que ha sido seleccionada una resistencia, se va a proceder al calculo de la máxima intensidad medible por el dispositivo:

V = I ∗ R; 31.25mV = i ∗ 50μΩ (6)

i = 625A (7)

Se ha de tener en cuenta que este valor es la amplitud máxima alcanzable, no la Irms. Para comprobar todos estos cálculos, se ha realizado una simulación con una resistencia de carga igual a 0.52Ω, lo que genera una intensidad pico de 625A, obteniendo como resultado en nuestras resistencias shunt:

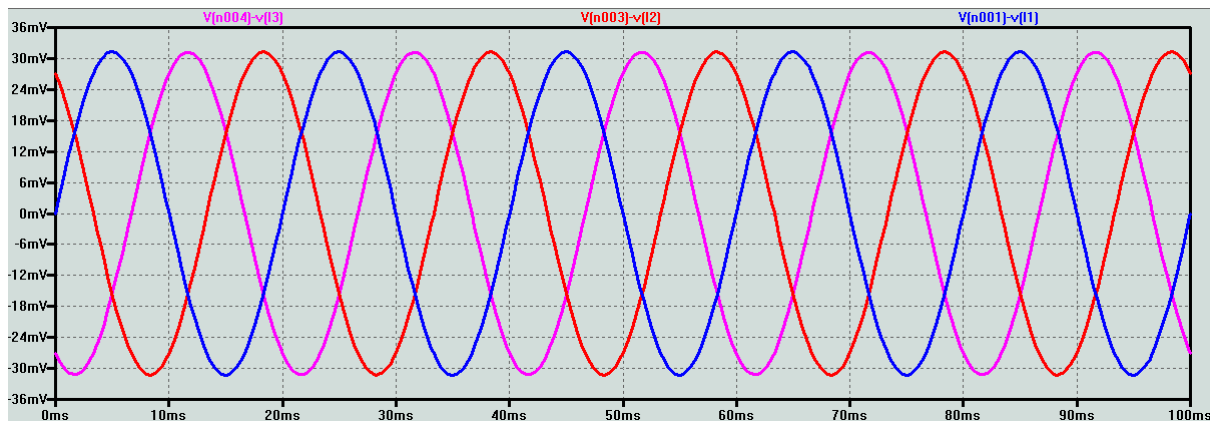
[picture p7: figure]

Figura 8: Señal de intensidad acondicionada para su medida.

### 1.4 Protocolo de comunicación SPI (Serial Peripheral Interface)

El protocolo SPI (Serial Peripheral Interface) es una interfaz de comunicación síncrona usado en comunicaciones de corta distancia, principalmente en los llamados sistemas empotrados. El protocolo fue elaborado por Motorola en los años ochenta y se ha convertido en uno de los mayores estándares de la industria electrónica.

El sistema tiene una comunicación full duplex usando una arquitectura maestro-esclavo, donde sólo puede haber un único maestro pero sí varios esclavos. Esto lo hace idóneo para su implementación en sistemas empotrados donde un único microprocesador PIC controla uno o varios circuitos integrados.

La principal ventaja de este sistema de comunicación es su versatilidad, dejando a decisión del diseñador cómo será su implementación. Esto, sin embargo, tiene los inconvenientes de que la implementación de un sistema a prueba de fallos tenga que ser vía software, junto con el tratamiento de los datos y el uso de los 4 pines necesarios para esta comunicación:

- SCLK (Signal Clock): Es el pin que transmite el pulso de sincronización. La gran ventaja del bus SPI es su gran versatilidad con este pin, ya que la frecuencia y los pulsos no tienen por qué ser regulares para una transmisión correcta de la información.
- MOSI (Master Output Slave Input): Pin usado para el envío de un dato por parte del maestro al esclavo.
- MISO (Master Input Slave Output): Pin usado para la recepción de un dato por parte del esclavo.
- SS (Signal Select): Cada esclavo se activará mediante un pin SS coordinado por el maestro. Esta es la mayor desventaja de un sistema de comunicación SPI, ya que requerirá de un uso excesivo de pines en el microcontrolador maestro.

Por lo tanto se ha decidido usar el protocolo de comunicación SPI para la transmisión de datos entre los sensores, el microcontrolador PIC y la raspberry Pi.

### 1.5 Puesta en marcha del ADE7912

Para un sistema con múltiples ADE7912 conectados a un microcontrolador y cuya frecuencia de reloj es suministrada gracias a un único cristal, habrá que seguir el siguiente procedimiento recomendado por el fabricante:

1. Suministrar Vdd a todos los dispositivos. Para garantizar un correcto encendido, la alimentación tiene que alcanzar los 2.97V en menos de 23ms desde el punto de los 2.6V. El primer dispositivo ADE7912A (fase A) estará conectado al cristal de 4.096 Mhz mientras que los demás dispositivos no están conectados aún a ninguna frecuencia de reloj.
2. El conversor DC-DC alimenta la parte protegida del circuito integrado. Es entonces cuando el modulador empieza a funcionar. Este proceso toma aproximadamente 100ms siempre y cuando el condensador recomendado para VDDiso haya sido colocado (figura 40). Después de este tiempo, el lado aislado galvánicamente del ADE7912A es totalmente funcional.
3. Para determinar cuando el ADE7912A está listo para aceptar comandos, se puede leer el registro STATUS0 y comprobar si su bit 0 está puesto en 0. Esto suele ocurrir a los 20ms del encendido.
4. Inicializar el registro CONFIG con el bit 0 puesto a 1. Esto habilitará la señal de reloj en el pin CLKOUT para los demás dispositivos.
5. El proceso de encendido de los otros 3 dispositivos ADE7912 se ejecutan tal y como se ha explicado en los pasos 2 y 3.
6. Inicializar correctamente los pines necesarios del registro CONFIG de todos los dispositivos, y conectar el pin DREADY del ADE7912C a una entrada del microcontrolador. Para esto el bit de CLKOUT del ADE7912C debe ser puesto a 0.
7. Inicializar el registro EMI_CTRL con los valores deseados.
8. Escribir en SYNC_SNAP un 0x01 de forma paralela en todos los dispositivos para empezar la lectura del ADC de todos los dispositivos en el mismo instante.
9. Bloquear la escritura de los registros de configuración.
10. Por último, cada unos pocos minutos comprobar la sincronización de las lecturas, tal y como se explicó en el apartado de sincronización de los ADE7912.

### 2. Actuadores

### 2.1 Relé de estado sólido

Un relé de estado sólido es un dispositivo electrónico capaz de interrumpir el paso de electricidad de una red de corriente alterna o continua. Este dispositivo electrónico es controlado por una señal de control aislada del sistema central y que en el caso de este proyecto, será una salida digital de 5V del sistema empotrado.

El relé de estado sólido no tiene partes mecánicas móviles (a diferencia de un relé normal), lo que conlleva un menor desgaste con el paso del tiempo. El relé de estado sólido (O SSR en inglés) utiliza semiconductores de potencia como tiristores y transistores, esto le permite poder cortar corrientes de muy alto amperaje y con una velocidad muy alta en comparación con los relés de partes mecánicas móviles.

El SSR G3PH-5150B DC5-24 con función de paso por zero que se ha elegido es capaz de conmutar tensiónes de hasta 480V y una intensidad de hasta 150A, podremos colocar tantos SSR como se requiera para poder controlar todos los dispositivos que se quieran controlar en el sistema. La única limitación viene dada por el número de salidas digitales del sistema empotrado, pero realizando un sistema de multiplexión, se podrán controlar tantos dispositivos como se necesiten.

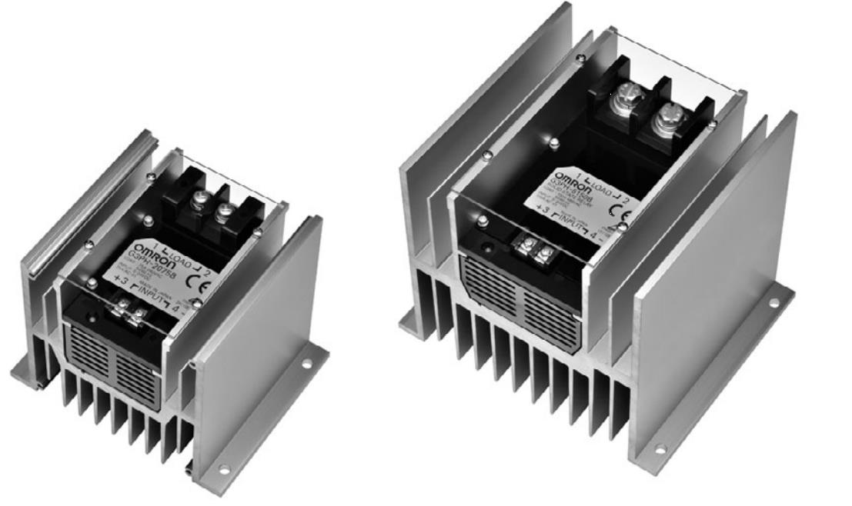
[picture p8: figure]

Figura 9: Relé de estado sólido G3PH-5150B DC5-24.

### 3. Diseño Hardware

El diseño hardware se ha repartido en tres secciones diferenciadas: El sistema de alimentación ininterrumpida, cuya finalidad es la generación de tensión de alimentación a 3.3V, 5V y carga de la bateria. La placa central, que alojará todos los circuitos integrados necesarios y que contará con las salidas necesarias para el GPIO de la raspberry pi. Por último, la placa de acondicionamiento de señales, donde se alojarán las resistencias shunt y los bornes de conexión para la red eléctrica. Como muestra del proceso seguido en el documento completo del TFG, se expone la figura 3D y el negativo del PCB de la placa principal:

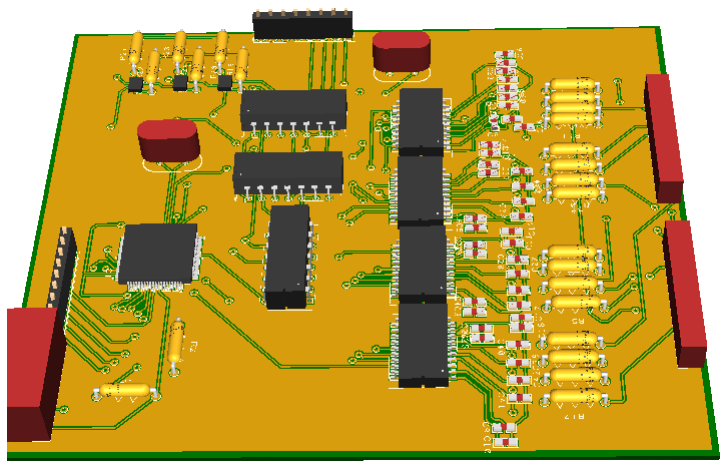
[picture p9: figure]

Figura 10: PCB placa principal en 3D.

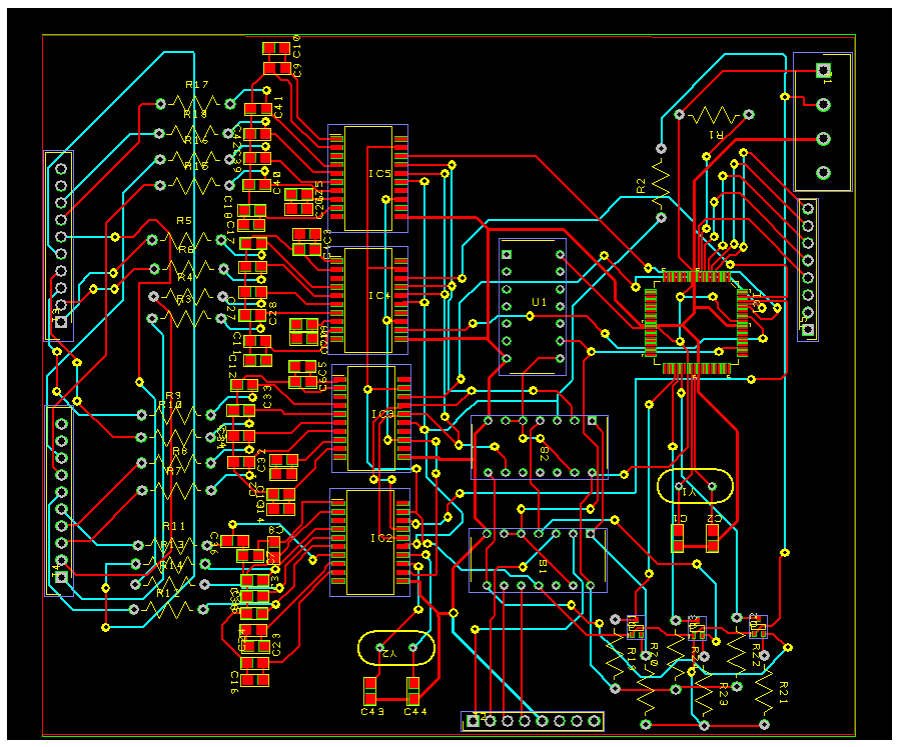
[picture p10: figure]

Figura 11: PCB placa principal en negativo.

### 4. Desarrollo software

El desarrollo software se va a separar en cuatro capas o niveles de programación: Sistema, web, aplicación android y GUI táctil. En la siguiente imagen se puede ver el diagrama de bloques del sistema:

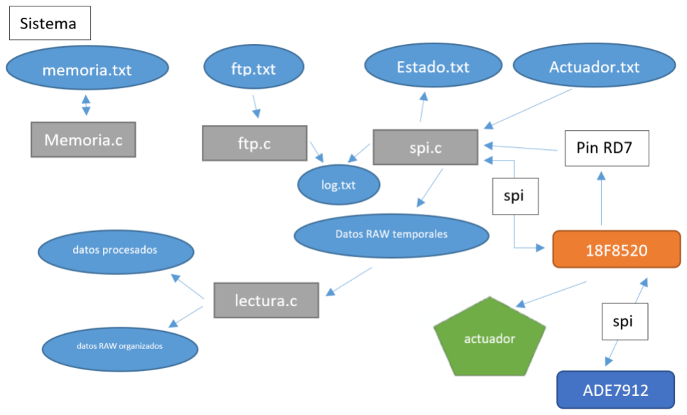
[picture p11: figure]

Figura 12: diagrama de bloques del sistema.

Nota: ‘datos raw’ son los archivos sin procesar del script spi.c, se almacenan los valores de la red eléctrica y tiempo relativo.

En el diagrama se pueden apreciar los archivos (en azul claro) que intervienen en el funcionamiento del sistema:

- Memoria.txt: Almacena el dato de la memoria ocupada por los datos raw. El script memoria.c lo crea y a su vez lo comprueba periódicamente.
- Ftp.txt: Archivo que almacena el estado del FTP (Activado – 1 o desactivado – 0). El script ftp.c comprueba periódicamente este fichero y se encarga de desactivar o activar el servidor ftp.
- Estado.txt: Archivo que almacena el estado de la red eléctrica (0 – Estable, 1- Corte).
- Actuador.txt: Archivo que almacena el estado del actuador. Si el contenido de este fichero es un 1, el script spi.c enviará de forma inmediata al PIC 18F8520 la orden de activar el actuador.
- Datos raw / Datos procesados: En primera instancia se tienen los datos raw por unidad de tiempo. Estos archivos raw desordenados los genera el script spi.c. Una vez por minuto, el script lectura.c lee estos datos, los procesa, y guarda dos copias de forma ordenada en la base de datos: Los datos procesados y los datos raw. Cuando esto es realizado, el script spi.c está capturando los nuevos datos raw del minuto siguiente.

- Log.txt: En el log se registran todos los eventos importantes del sistema así como la fecha y hora en el que se han producido.

A continuación se puede apreciar el diagrama de bloques de la capa del servidor web y la capa de la aplicación móvil:

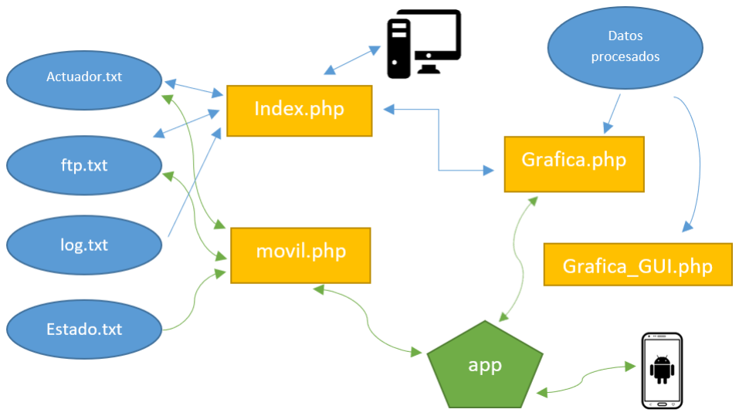
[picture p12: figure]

Figura 13: Diagrama de bloques servidor web y aplicación android

Capa servidor web:

- Index.php: Página web que presenta la gráfica seleccionada, permite actuar y leer los estados del actuador y del servidor ftp, y además muestra el log.txt para poder ver los eventos del sistema.
- Grafica.php: Al pasarle por url los parámetros de la gráfica requerida, devuelve una imagen de los datos correspondientes al día de la petición. Dichos datos los coge de la base de datos.
- Grafica_GUI.php: De igual forma que grafica.php, devuelve los parámetros de la gráfica requerida, sin embargo los devuelve en una imagen con una resolución especial para la interfaz gráfica requerida en la pantalla táctil. Se explicará con más detalle más adelante.

Capa aplicación móvil:

- Movil.php: Permite leer y actuar sobre el actuador y el servidor ftp (mediante sus respectivos ficheros .txt) y permite leer el estado actual de la red (estado.txt).
- App: Aplicación programada en Java que se conecta a movil.php y Grafica.php para obtener todos los datos necesarios para mostrar en la aplicación móvil. También permite activar o desactivar el actuador y servidor FTP.

Por último, se tiene el diagrama de la capa de la interfaz gráfica de la pantalla táctil:

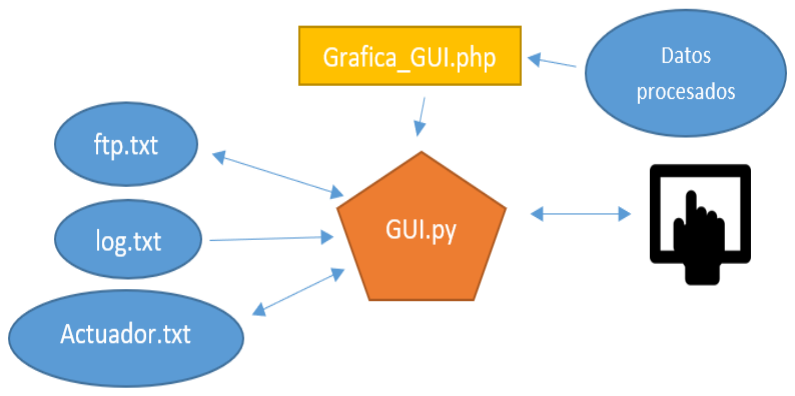
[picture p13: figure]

Figura 14: Diagrama de bloques interfaz gráfica

Como se puede ver en la imagen anterior, la interfaz gráfica y aplicación de la pantalla táctil está controlada por un archivo python central, el cual coge el archivo log.txt para mostrar todos los eventos del sistema, usa a su vez un script en el servidor web para descargarse las imágenes de las gráficas que se van a mostrar, y controla el estado del servidor FTP y del actuador a través de los ficheros de texto correspondientes.

Debido a la baja resolución de pantalla que posee la pantalla LCD táctil que se dispone, se ha tenido que modificar el script grafica.php y crear uno secundario (grafica_gui.php) para la creación de las gráficas en un formato y resolución acorde con la pantalla táctil.

### 5. Diagramas de flujo

### 5.1 Sistema

PIC18F8520
Se va empezar con el diagrama de flujo del código grabado en el PIC 18f8520:

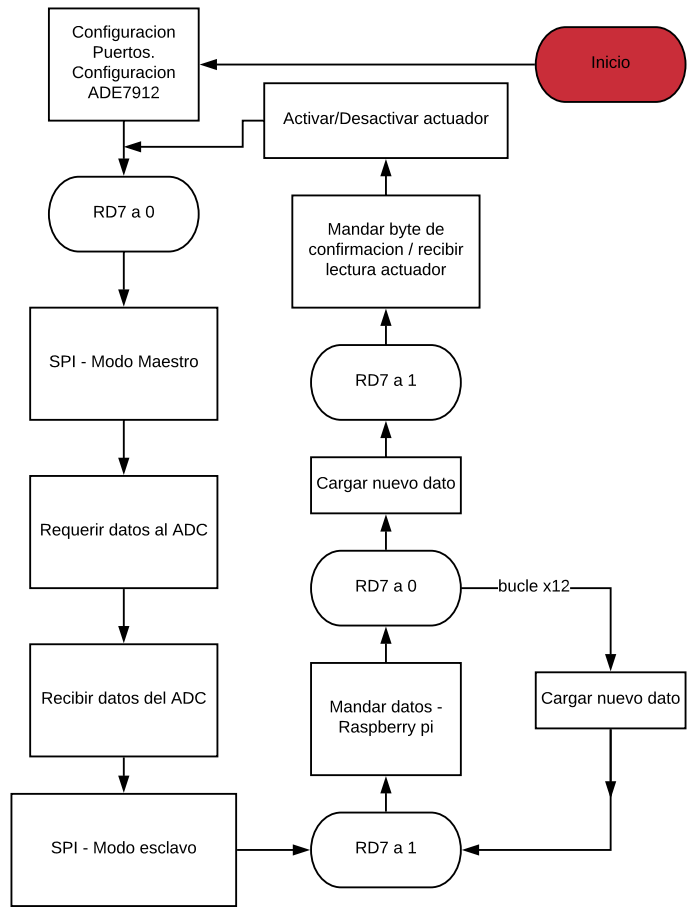
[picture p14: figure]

Figura 15: Diagrama de flujo PIC

Como se puede apreciar, se envian 12 bytes más uno de confirmación. Estos 12 bytes son los datos de 24 bits de resolución que ofrece el ADE7912. Estos datos son la intensidad, el voltaje circulante y la temperatura. Como se puede ver, el pin RD7 controla la comunicación entre el ADC y la raspberry pi.

SPI.c
A continuación se tiene el diagrama de flujo del script spi.c:

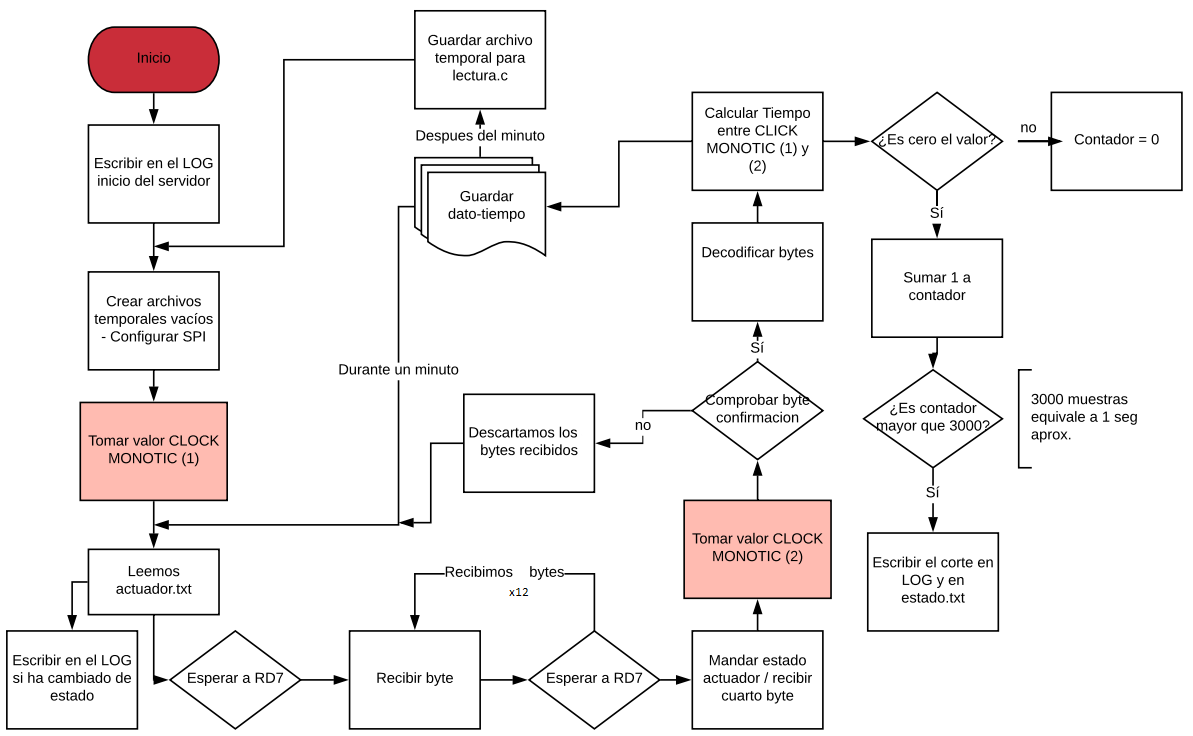
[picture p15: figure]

Figura 16: Diagrama de flujo script SPI

Como se puede apreciar en el diagrama de flujo, una vez arrancado el script no se detendrá hasta que se pare de forma manual. El script lee todos los datos del PIC durante un minuto y los almacena diferentes archivos de texto que posteriormente lectura.c coge para su tratamiento. A la vez que realiza la operación de obtención de datos, también detecta en tiempo real los cortes en la alimentación y manda activar/desactivar al actuador depende de como lo ordenemos en el archivo de texto.

Se utiliza la función CLOCK MONOTIC de raspberry pi ya que es una función especialmente diseñada para la temporización, ya que es un contador que no depende de la fecha actual recolectada de un servidor, sino que siempre va en aumento, por ello es totalmente fiable y siempre que restemos el valor (1) al valor
(2) obtendremos un valor positivo en microsegundos.

También se puede observar como los datos (Tanto intensidad, voltaje como temperatura) son descartados si el byte de confirmación recibido es erróneo. De esta forma se pueden evitar los valores incorrectos debido a la desincronización entre dispositivos.

lectura.c
En la siguiente figura se muestra el diagrama de flujo del script encargado de la trata de datos:

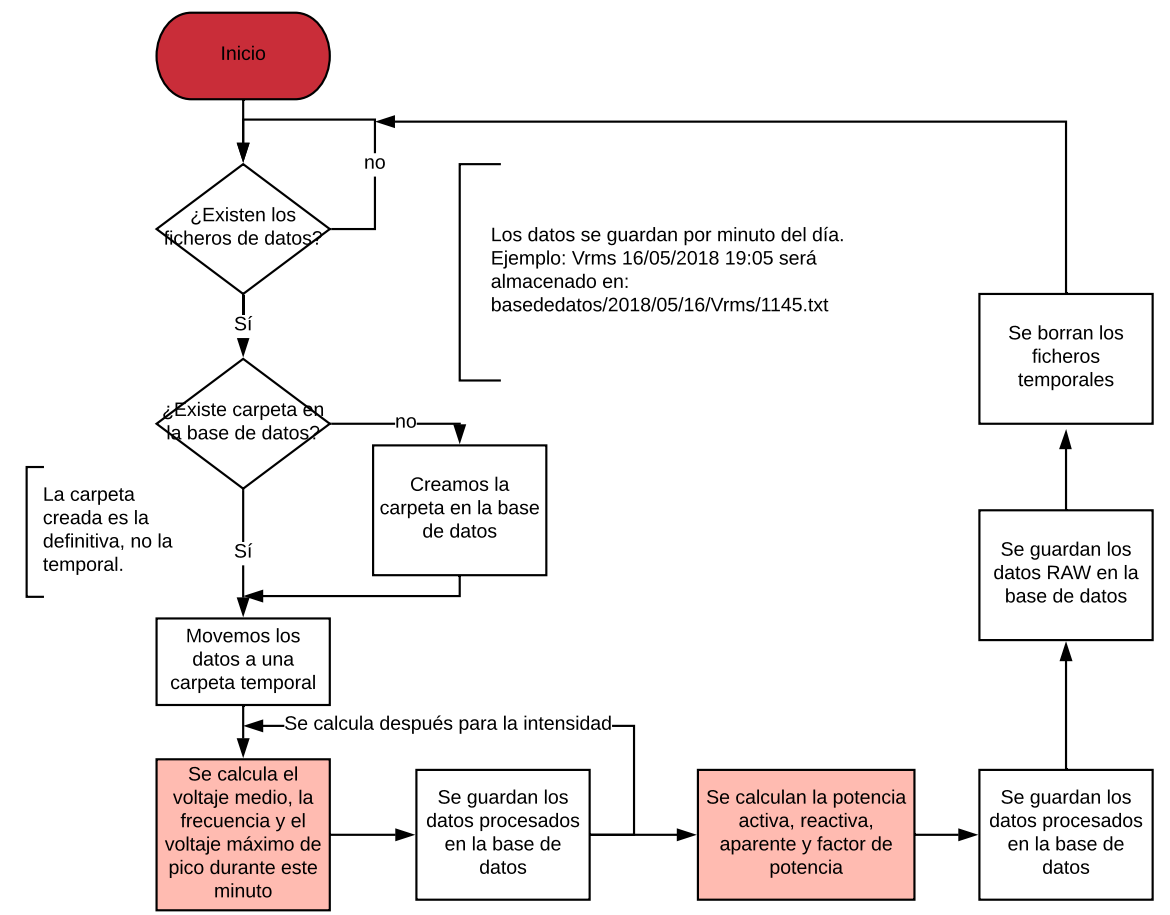
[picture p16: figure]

Figura 17: Diagrama de flujo script lectura

Primero se entra en un bucle infinito hasta que spi.c le cede los datos raw. Entonces crea la carpeta oportuna en la base de datos (según la fecha en la que se encuentre el sistema) y mueve los ficheros creados por el script spi.c hacia una carpeta temporal. Se calculan los valores medios de Vrms e Irms, Ifrec, Vfrec y Ipico, Vpico. Una vez que se tienen estos 6 datos calculados, se procede a calcular la potencia activa, reactiva y aparente del sistema, junto con el factor de potencia.

### 5.2 Servidor web

Index.php
En la siguiente figura se puede ver el resultado final del servidor web:

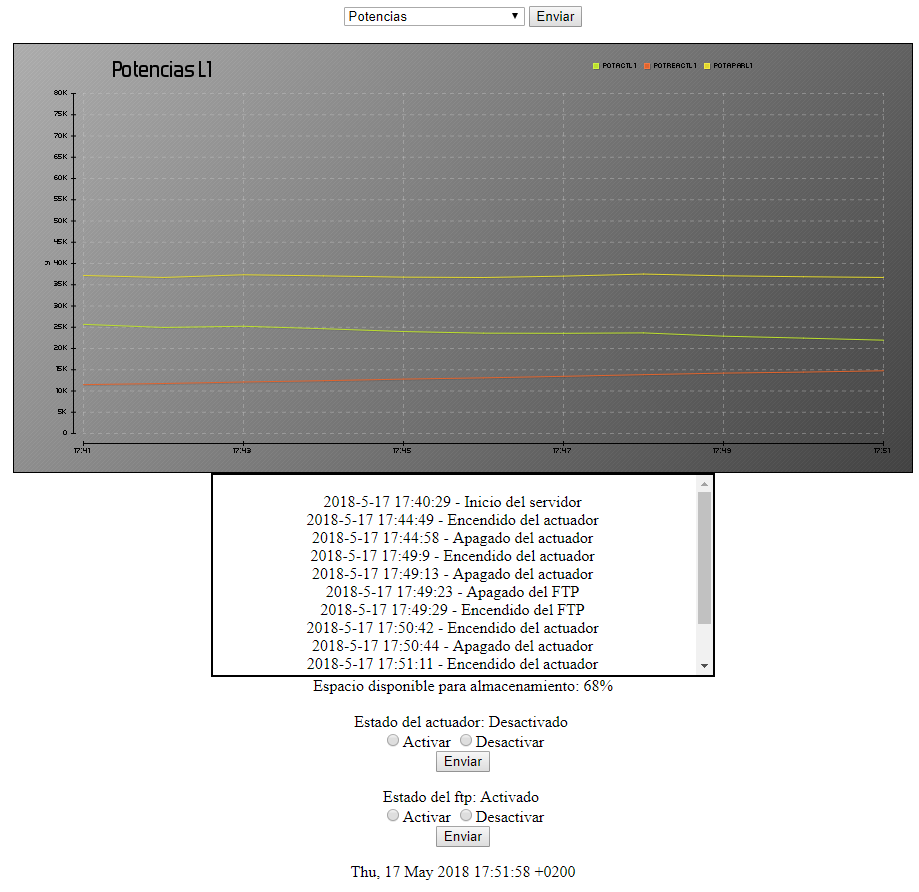
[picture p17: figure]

Figura 18: Página web.

Como se puede apreciar, se muestra la gráfica de las potencias en nuestro sistema (Aparente en amarillo, Activa en verde y reactiva en rojo). Con el primer botón de “enviar” junto con la lista desplegable podremos seleccionar que gráfica mostrar entre: Vrms/Irms, Potencias, frecuencias y factor de potencia.

También se puede ver como el log está presentado dentro de una caja de texto con un scroll vertical donde podremos ver todos los eventos importantes del sistema. Junto con esta caja de texto contamos con el estado del actuador y del ftp, ambos accionables desde la página web.

A continuación se pone el diagrama de flujo:

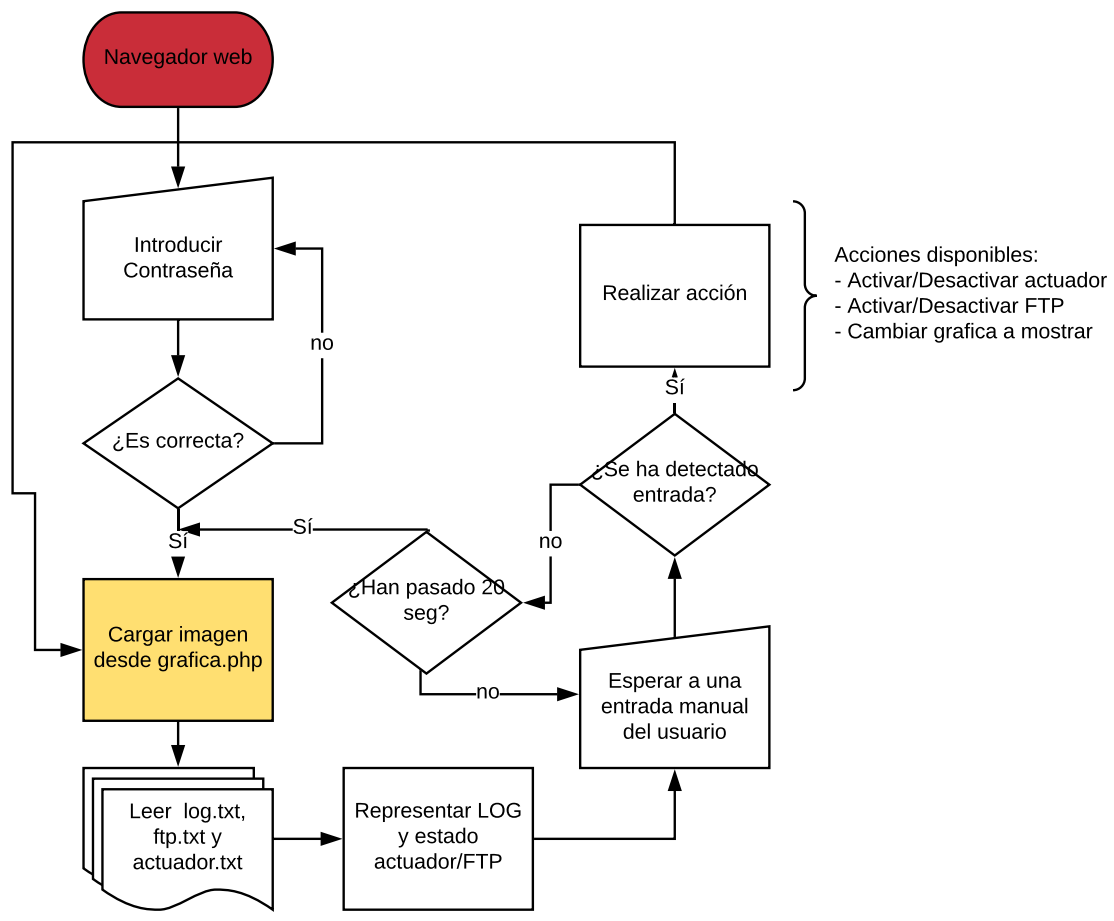
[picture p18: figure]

Figura 19: Diagrama de flujo pagina web.

Lo primero que se pide es acceder con una contraseña. En este caso se ha seleccionado ‘rubenelportero’ para tal efecto. Una vez que hemos introducido la contraseña, el sistema pedirá la gráfica al archivo grafica.php (la función que genera la representación que se le pida). Después lee el archivo log, ftp y actuador y representa toda la información recogida en el navegador web desde el cual se está accediendo. Esperamos a una entrada manual del usuario (activar/desactivar actuador-ftp o cambiar de gráfica a representar) y si no se ha realizado ninguna entrada manual en 20 segundos, la página se recargará automáticamente.

### 5.3 GUI táctil

gui.py
En las siguientes capturas se puede apreciar la interfaz gráfica desarrollada para la pantalla táctil:

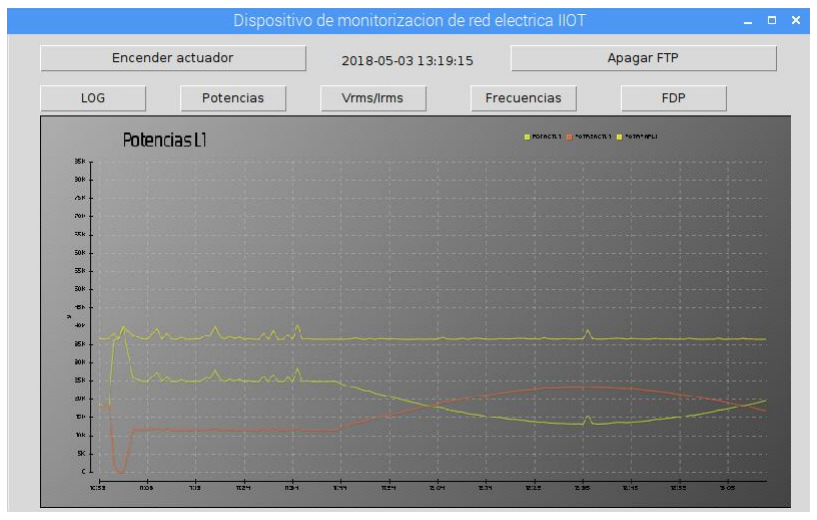
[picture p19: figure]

Figura 20: Interfaz gráfica táctil.

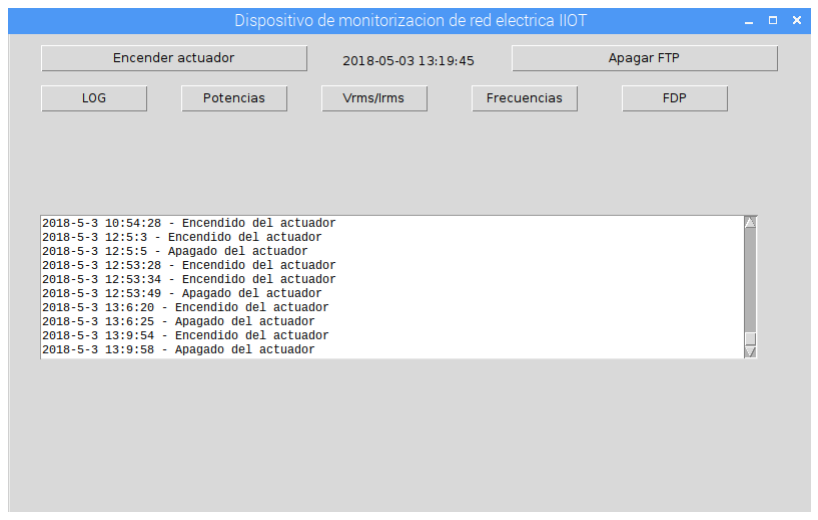
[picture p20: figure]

Figura 21: Interfaz gráfica táctil.

Como se puede apreciar, disponemos de un total de 5 botones para seleccionar entre los datos que se quieren mostrar y dos botones más para activar o desactivar el actuador y el ftp (A la vez que se muestran sus estados actuales).

El diagrama de flujo se muestra en la siguiente imagen:

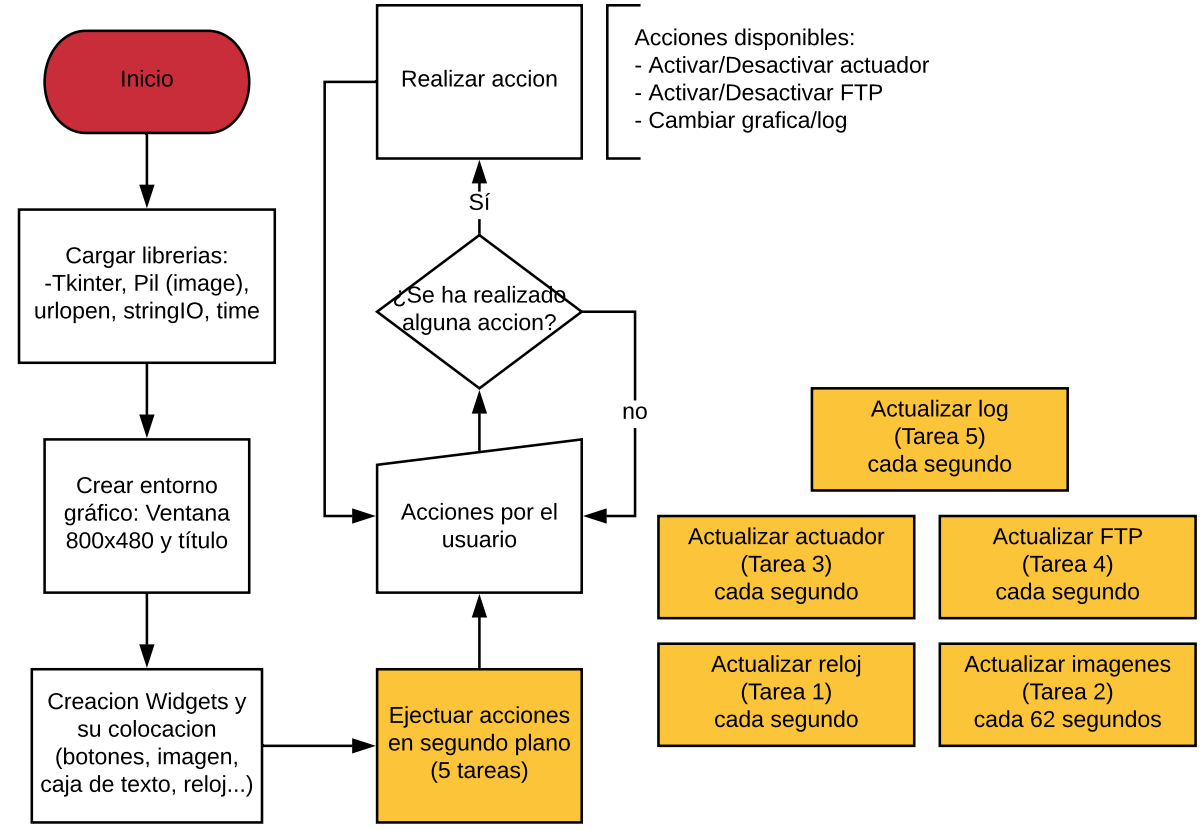
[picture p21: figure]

Figura 22: Diagrama de flujo interfaz gráfica.

Primeramente se cargan las librerias necesarias para el tratamiento de los datos leídos. Seguidamente se colocan los widgets en su respectivo lugar y se inician todas las acciones que se ejecutan en segundo plano. Una vez todo representado en pantalla, simplemente se espera a que el usuario pulse alguno de los botones que se muestran por pantalla para realizar la acción requerida.

Las cinco tareas en segundo plano son la siguientes:

1. Actualizar el reloj (A cada segundo).
2. Actualizar imágenes: Se descargarán todas las imágenes del servidor (Grafica_GUI.php) y se guardan en la carpeta de la interfaz gráfica, así la navegación entre gráficas es más fluida cuando vamos interactuando con la interfaz gráfica.
3. Actualizar actuador: A cada segundo leemos el archivo actuador.txt para ver si se ha producido algún cambio en el actuador desde otro periférico: La aplicación en android o el servidor web.
4. Actualizar FTP: A cada segundo leemos el archivo ftp.txt para comprobar si se ha producido algún cambio desde otro periférico: La aplicación para android o desde el servidor web.
5. Actualizar LOG: A cada segundo borramos todo el texto disponible en la caja de texto y re-escribimos el contenido de LOG.txt. Esto lo realizamos para estar totalmente actualizados de los eventos que ocurren en el sistema.

### 5.4 Aplicación móvil para Android

La aplicación móvil esta compuesta por un proyecto en android studio disponible en el CD del trabajo.

A continuación se exponen unas imágenes de la aplicación móvil:

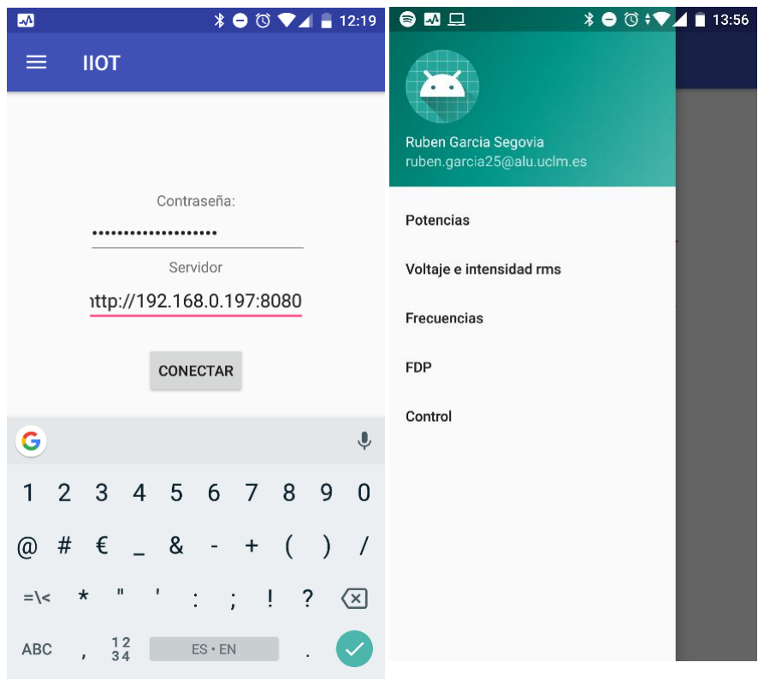
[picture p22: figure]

Figura 23: Capturas de pantalla de la aplicación

Como se puede ver en las imágenes, se ha utilizado un estilo conocido como material design (diseñada por google) que ofrece una interfaz clara y sencilla de utilizar, aparte de ajustarse de manera correcta a todo tipo de pantallas y teléfonos. Sin embargo, a la hora de representar las gráficas se expone la imagen descargada del servidor con una resolución y zoom específico para móviles con pantalla táctil de 5,5 pulgadas.

Todo el proceso de programación, diagramas de flujo y ecosistema de android viene explicado en detalle en el documento completo del TFG.

### 6. Montaje

Debido a la limitación de componentes electrónicos disponibles en la Universidad, se ha realizado el siguiente montaje en el laboratorio:

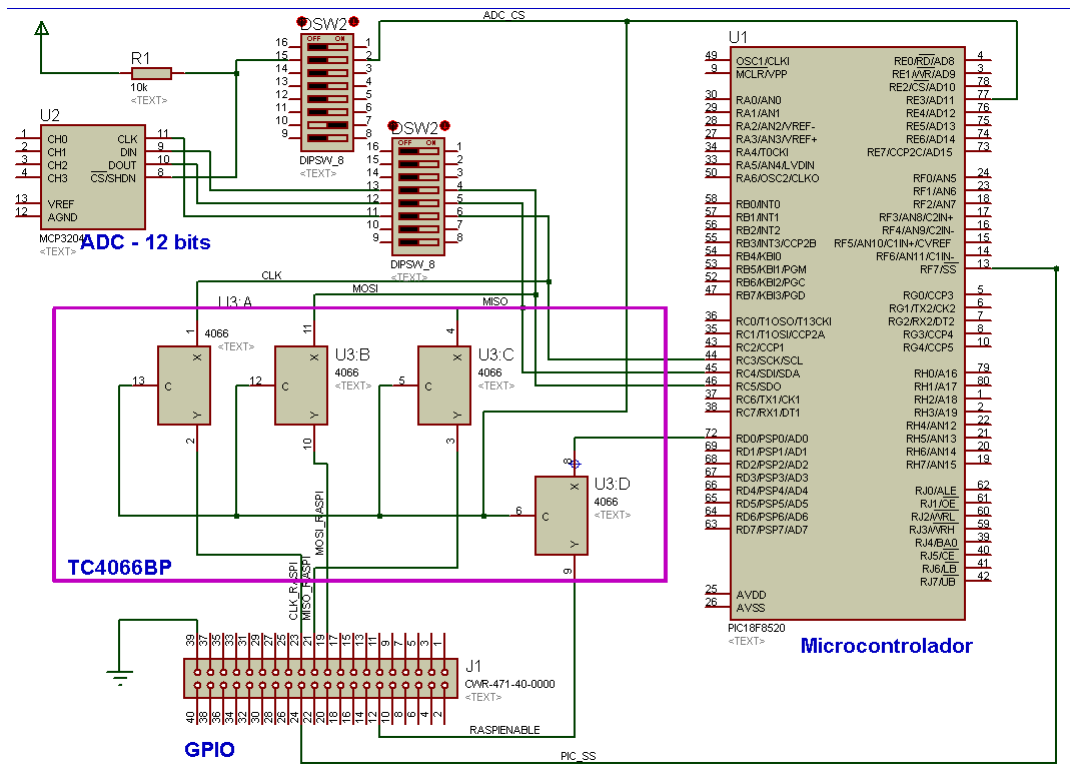
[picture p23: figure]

Figura 24: Montaje para la captación de datos.

Como se puede apreciar, el circuito está simplificado respecto al circuito hardware diseñado anteriormente, sin embargo, es suficiente para realizar las pruebas en el laboratorio y comprobar la viabilidad del proyecto.

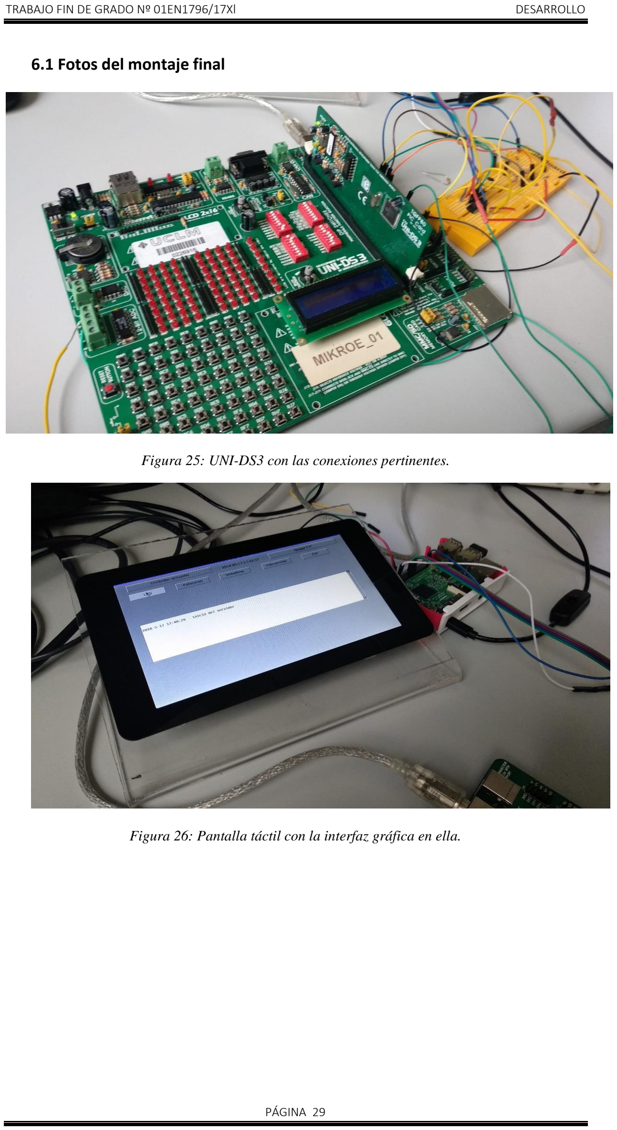
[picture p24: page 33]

### 6.1 Fotos del montaje final

Figura 25: UNI-DS3 con las conexiones pertinentes.

Figura 26: Pantalla táctil con la interfaz gráfica en ella.

TRABAJO FIN DE GRADO Nº 01EN1796/17Xl | CONCLUSIONES Y TRABAJOS FUTUROS

# CONCLUSIONES Y TRABAJOS FUTUROS

Al término de este Trabajo Fin de Grado, se recogen una serie de conclusiones descritas a continuación:

En primer lugar, se comprueba cómo un alumno que ha superado con éxito todas las asignaturas que este grado propone es capaz de identificar una necesidad, o una posible mejora en un determinado proceso (en este caso, en una instalación eléctrica), y aplicar los conocimientos no sólo aprendidos a lo largo de su etapa estudiantil, sino aprendiendo e investigando nuevos campos de la ingeniería y del conocimiento para resolver el problema de la mejor forma posible. En este caso específico, se han utilizado conocimientos de tres campos distintos de la ingeniería: informática, electrónica y electricidad para el diseño integral de una solución IIOT (Industrial Internet Of Things). A pesar de los recursos limitados con los que se cuentan en la Escuela de Ingenieros Industriales de Albacete, ha sido posible diseñar el sistema de forma teórica y de una forma práctica, quedando así demostrado la viabilidad del proyecto llevado a cabo.

Se ha podido comprobar también cómo las nuevas tecnologías tienden a convertirse en sistemas autónomos en un solo encapsulado, siendo prácticamente una pérdida de tiempo diseñar por uno mismo una solución específica. Esto se ha podido ver claramente con el encapsulado ADE7912, donde podemos ver que la industria ha diseñado un circuito integrado que recoge una señal analógica, la convierte a señal digital junto con una barrera de separación galvánica y habilitando al ingeniero su uso en una alta gama de microcontroladores disponibles. Esto, además, muestra el interés de los fabricantes por impulsar el IIOT/IOT y la monitorización eléctrica, cada vez más presente en hogares y fábricas. Sobre todo con la llegada de las Smart Cities, la revolución de los coches eléctricos y las energías renovables, un tema que daría para otro Trabajo Fin de Grado completo.

Por último, se ha demostrado el potencial del software libre y tener una comunidad detrás de ella, habiendo usado para este proyecto numerosos software con licencias de este estilo: Python, PHP, Android, Raspbian, Apache... A parte de haber encontrado ayuda y tutoriales de aprendizaje de forma desinteresada en sitios web como StackOverFlow y GitHub. Por este mismo motivo, y para fomentar la investigación, aprendizaje y mejora de este proyecto, se ha licenciado este TFG bajo una licencia Creative Commons.

TRABAJO FIN DE GRADO Nº 01EN1796/17Xl | CONCLUSIONES Y TRABAJOS FUTUROS

En cuanto a trabajos futuros se recogen varias líneas de mejora:

- Fabricación de las placas PCB diseñadas. Debido a no tener la tecnología de fabricación de PCB disponible, no se han podido fabricar las placas de circuito impreso, por ello se ha dejado el desarrollo teórico de las mismas para ser aplicado en un futuro.
- Implementación de red GSM para el envío de los datos a través de internet de una forma totalmente autónoma e inalámbrica, permitiendo así colocar el sistema en fábricas o ubicaciones de difícil acceso o sin conexión a internet.
- Seguridad: A pesar de haber instalado una contraseña de acceso a ciertas áreas de la página web, un punto a mejorar es la seguridad del servidor, ya que de preparar el servidor para ser accesible mediante internet (con la ip externa de nuestra instalación) puede ser fácilmente controlada por algún Cracker.
- Dotar al software de mayor adaptación y configurabilidad: En este trabajo no es posible, pero un sistema de alertas o accionadores automáticos podría mejorar mucho el sistema. Por ejemplo: Cuando la tensión de Vl1 baje de 180V, desactivar el actuador1 de forma automática, y activar el actuador2.
- Análisis de armónicos: Aunque se poseen los datos sin procesar necesarios para analizar el espectro frecuencial de nuestra instalación usando un software específico, se podría haber implementado una FFT en algún lenguaje de programación.
- Realización de cajón: Modelar un cajón o caja donde incluir toda la electrónica del sistema y poder colocarla en la pared junto con el cuadro eléctrico monitorizado.
- Detección de errores y fallos: El sistema actual sólo posee un sistema de detección de corte en la red eléctrica. Se pueden programar la detección de múltiples errores y problemas: Desequilibrios, bajadas de tensión, huecos de tensión, sobretensiones, armónicos, etc.

TRABAJO FIN DE GRADO Nº 01EN1796/17Xl | Bibliografía

# BIBLIOGRAFÍA

1. PIC 18F8520 Datasheet: Microchip Technology.
2. ADE7912 Datasheet: Analog Devices.
3. Relé de estado solido G3PH Datasheet: Omron.
4. TC4066BP Datasheet: Toshiba
5. Resistencia Shunt Datasheet: Vishay.
6. DM7404 Datasheet: Fairchild.
7. BSS138 Datasheet: Infineon.
8. Uni-DS3 manual de usuario: MikroElectronika.
9. MSP3204 Datasheet: Microchip Technology.
10. David Lineweber y Shawn Mcnulty. (2001).The Cost of Power Disturbances to Industrial & Digital Economy Companies, Primen.
11. Jose Salas. 2013. Comunicación entre dos pics maestro-esclavo mediante SPI. Link: http://todoelectrodo.blogspot.com.es/2013/03/comunicacion-entre-2-pics-maestro.html (http://todoelectrodo.blogspot.com.es/2013/03/comunicacion-entre-2-pics-maestro.html)
12. WiringPi Library. Link: http://wiringpi.com/
13. Raspberry Pi Foundation. Link: https://www.raspberrypi.org/
14. Python Software Foundation. Link: https://www.python.org/
15. Tkinter library. Link: https://wiki.python.org/moin/TkInter
16. Joan Ribas Lequerica. 2013. Desarrollo de aplicaciones para android, Anaya
17. David Sastre. 2012. Descargar imagen desde URL en android. Link: https://sekthdroid.wordpress.com/2012/11/29/descargar-imagen-desde-url-en-android/ (https://sekthdroid.wordpress.com/2012/11/29/descargar-imagen-desde-url-en-android/)
18. Pchart library. Link: http://www.pchart.net/
19. Rubén García Segovia. MakingBytes. Link: https://github.com/rubenelportero/MakingBytes
20. AENOR. Características de la tensión suministrada por las redes generales de distribución. UNE-EN 50160, 2015.

TRABAJO FIN DE GRADO Nº 01EN1796/17Xl | LICENCIA DE USO

# LICENCIA DE USO

Rubén García Segovia, autor de este trabajo fin de grado, pongo todo el documento, excepto anexos, bajo la licencia Creative Commons internacional 4.0 de reconocimiento y compartir igual.

Bajo esta licencia, usted está autorizado a leer, redistribuir, cambiar, adaptar y hacer uso comercial de esa obra siempre y cuando se cumplan los siguientes términos y condiciones:

1. Dar autoría al autor original de la obra (Rubén García Segovia – https://github.com/rubenelportero/).
2. Poner su trabajo bajo esta misma licencia u otra similar.

Para leer la licencia completa u obtener más información, visitar el siguiente enlace o ver la licencia completa adjuntada en el CD (En inglés):

https://creativecommons.org/licenses/by-sa/4.0/legalcode

El anexo 1 queda exento de esta licencia debido a que se trata de datasheets y hojas de fabricante, material con licencias propietarias que dependen únicamente de los fabricantes.

El anexo 2, junto con todo el código de programación en los distintos lenguajes de programación usados y adjuntados en este trabajo están bajo la licencia GLPv3 de GNU, siendo código de software libre, permitiendo la modificación, redistribución, mejora e incluso uso comercial de todo el código incluido en el trabajo de fin de grado siempre y cuando se mantenga la licencia. Para más detalles, revisar la licencia completa en la siguiente url o ver la licencia completa adjuntada en el CD (En inglés):

https://www.gnu.org/licenses/gpl-3.0.html

Todo el proyecto está disponible en el repositorio GitHub correspondiente:

https://github.com/rubenelportero/Design-of-a-electrical-networking-and-control-system (https://github.com/rubenelportero/Design-of-a-electrical-networking-and-control-system)

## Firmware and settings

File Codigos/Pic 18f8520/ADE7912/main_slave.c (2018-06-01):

// Ruben Garcia Segovia
// ADC UNIDS-3 conectado por SPI junto con la Raspberry Pi 
// Simulando al conversor ADE7912.

// Librerias
#include "spi.h"
#include <delays.h>
#include <p18f8520.h>

//Configuracion del pic
#pragma config OSC= HS, WDT = OFF, LVP = OFF

//Los cuatro Bytes del ADC que se van a leer
char response1_1 = 0x00;
char response1_2 = 0x00; //Voltaje
char response1_3 = 0x00;
char response1_4 = 0x00;

char response2_1 = 0x00;
char response2_2 = 0x00; //Intensidad
char response2_3 = 0x00;
char response2_4 = 0x00;

char response3_1 = 0x00;
char response3_2 = 0x00; //Temperatura
char response3_3 = 0x00;
char response3_4 = 0x00;

//El dato recibido de la raspberry
char Raspi_spi = 0x00;
int contador = 0; //Contador = 0 para LN, 1 para L1, 2-L2, 3-L3
float sincro = 3840000; //Cada 2 minutos contabilizados...

//Son cuatro char, ya que guardamos las dos respuestas del conversor analógico digital
//Ya que tenemos dos datos a recuperar de 24 bits.
 
void main(void) {
	TRISDbits.TRISD0 = 1; //Aviso del ADE7912 Para saber cuando debemos pedir datos
	TRISDbits.TRISD7 = 0; //Para gobernar la raspberry pi
	TRISGbits.TRISG0 = 0; //Para gobernar el actuador
	TRISB=0XFF;
	TRISE=0X00;//gobernar todos los ADE7912
	LATE=0xFF;   //Para gobernar el ADC y la raspberry;
	LATGbits.LATG7=0; 

	//INICIO CONFIGURACION //

	LATDbits.LATD7=0; //Iniciamos RD7 a 0 para avisar a la raspberry pi.
	OpenSPI(SPI_FOSC_16,MODE_11,SMPEND); //Iniciamos SPI como maestro
	while(SSPBUF==1) {  //Comprueba que el ADC0 esté listo y lo configura
		LATEbits.LATE2=0; 
		WriteSPI(0x4C);
		ReadSPI();
		SSPBUF = SSPBUF&0x01;
		LATEbits.LATE2=1;
	}
	LATEbits.LATE2=0; 
	WriteSPI(0x40); //Registro de configuracion
	WriteSPI(0x81); //8Khz, BW seleccionado, modo multiples ADC...
	WriteSPI(0xE0); //Registro EMI
	WriteSPI(0xAA); 
	LATEbits.LATE2=1;

	while(SSPBUF==1) {  //Comprueba que el ADC1 esté listo y lo configura
		LATEbits.LATE3=0; 
		WriteSPI(0x4C);
		ReadSPI();
		SSPBUF = SSPBUF&0x01;
		LATEbits.LATE3=1;
	}
	LATEbits.LATE3=0; 
	WriteSPI(0x40); //Registro de configuracion
	WriteSPI(0x81); //8Khz, BW seleccionado, modo multiples ADC...
	WriteSPI(0xE0); //Registro EMI
	WriteSPI(0xAA);
	LATEbits.LATE3=1;

	while(SSPBUF==1) {  //Comprueba que el ADC2 esté listo y lo configura
		LATEbits.LATE4=0; 
		WriteSPI(0x4C);
		ReadSPI();
		SSPBUF = SSPBUF&0x01;
		LATEbits.LATE4=1;
	}
	LATEbits.LATE4=0; 
	WriteSPI(0x40); //Registro de configuracion
	WriteSPI(0x81); //8Khz, BW seleccionado, modo multiples ADC...
	WriteSPI(0xE0); //Registro EMI
	WriteSPI(0x55);
	LATEbits.LATE4=1;

	while(SSPBUF==1) {  //Comprueba que el ADC3 esté listo y lo configura
		LATEbits.LATE5=0; 
		WriteSPI(0x4C);
		ReadSPI();
		SSPBUF = SSPBUF&0x01;
		LATEbits.LATE5=1;
	}
	LATEbits.LATE5=0; 
	WriteSPI(0x40); //Registro de configuracion
	WriteSPI(0x81); //8Khz, BW seleccionado, modo multiples ADC...
	WriteSPI(0xE0); //Registro EMI
	WriteSPI(0x55);
	LATEbits.LATE5=1;

	//FIN CONFIGURACION //

	while(1){  //De forma indefinida...
	if(sincro>= 3840000) {
		LATEbits.LATE2=0;   //Llamada simultanea a todos los ADC 
		LATEbits.LATE3=0; 
		LATEbits.LATE4=0; 
		LATEbits.LATE5=0; 
		WriteSPI(0xB0); //Sync_snap
		WriteSPI(0x01); //Reset y sincronizacion
		LATEbits.LATE2=1;   //Llamada simultanea a todos los ADC 
		LATEbits.LATE3=1; 
		LATEbits.LATE4=1; 
		LATEbits.LATE5=1; 
		sincro = 0;
	}
	while(PORTDbits.PORTD0==1||contador>0); // Hasta que no nos avise el ADC de que está listo.
	switch(contador){
		case 0:
			LATEbits.LATE2=0;
			break;
		case 1:
			LATEbits.LATE3=0;
			break;
		case 2:
			LATEbits.LATE4=0;
			break;
		default:
			LATEbits.LATE5=0;
			break;
	}
	WriteSPI(0x04); //IWV
	ReadSPI();
	response1_1=SSPBUF;
	ReadSPI();
	response1_2=SSPBUF;
	ReadSPI();
	response1_3=SSPBUF;
	ReadSPI();
	response1_4=SSPBUF;
	WriteSPI(0x0C); //V1WV
	ReadSPI();
	response2_1=SSPBUF;
	ReadSPI();
	response2_2=SSPBUF;
	ReadSPI();
	response2_3=SSPBUF;
	ReadSPI();
	response2_4=SSPBUF;
	WriteSPI(0x14); //V2WV (Temperatura)
	ReadSPI();
	response3_1=SSPBUF;
	ReadSPI();
	response3_2=SSPBUF;
	ReadSPI();
	response3_3=SSPBUF;
	ReadSPI();
	response3_4=SSPBUF;
	switch(contador){
		case 0:
			LATEbits.LATE2=1;
			contador++;
			break;
		case 1:
			LATEbits.LATE3=1;
			contador++;
			break;
		case 2:
			LATEbits.LATE4=1;
			contador++;
			break;
		default:
			LATEbits.LATE5=1;
			contador = 0;
			break;
	}
		
/****************************************************************************/
	//                   VOLTAJE   //
	Nop();
	Nop();	 //Le dejamos un poco para que no sea inmediato
	Nop();
	OpenSPI(SLV_SSON,MODE_00,SMPEND); //Iniciamos SPI en modo ESCLAVO.
	SSPBUF = response1_1; //Cargamos el primer byte
	Nop();
	while(!SSPSTATbits.BF){  //Esperamos a que lo recojan
		LATD = 0XFF;  //Activamos el PIN RASPIENABLE
	}
	LATD = 0X00;
	Raspi_spi = SSPBUF; //Recuperamos el dato recibido

	SSPBUF = response1_2; //Cargamos el segundo byte
	Nop();
	while(!SSPSTATbits.BF){ //Esperamos a que lo recojan
		LATD=0XFF; //Activamos el PIN RASPIENABLE
	}
	LATD=0X00;
	Raspi_spi = SSPBUF; //Recuperamos el dato recibido

	SSPBUF = response1_3; //Cargamos el tercer byte
	Nop();
	while(!SSPSTATbits.BF){ //Esperamos a que lo recojan
		LATD=0XFF; //Activamos el PIN RASPIENABLE
	}
	LATD=0X00;
	Raspi_spi = SSPBUF; //Recuperamos el dato recibido

	SSPBUF = response1_4;	//Cargamos el cuarto byte
 	Nop();
	while(!SSPSTATbits.BF){ //Esperamos a que lo recojan
		LATD=0XFF; //Activamos el PIN RASPIENABLE
	}
	LATD=0X00;
	Raspi_spi = SSPBUF; //Recuperamos el dato recibido

	//            INTENSIDAD          //
	SSPBUF = response2_1; //Cargamos el primer byte
	Nop();
	while(!SSPSTATbits.BF){  //Esperamos a que lo recojan
		LATD = 0XFF;  //Activamos el PIN RASPIENABLE
	}
	LATD = 0X00;
	Raspi_spi = SSPBUF; //Recuperamos el dato recibido

	SSPBUF = response2_2; //Cargamos el segundo byte
	Nop();
	while(!SSPSTATbits.BF){ //Esperamos a que lo recojan
		LATD=0XFF; //Activamos el PIN RASPIENABLE
	}
	LATD=0X00;
	Raspi_spi = SSPBUF; //Recuperamos el dato recibido

	SSPBUF = response2_3; //Cargamos el tercer byte
	Nop();
	while(!SSPSTATbits.BF){ //Esperamos a que lo recojan
		LATD=0XFF; //Activamos el PIN RASPIENABLE
	}
	LATD=0X00;
	Raspi_spi = SSPBUF; //Recuperamos el dato recibido

	SSPBUF = response2_4;	//Cargamos el cuarto byte
 	Nop();
	while(!SSPSTATbits.BF){ //Esperamos a que lo recojan
		LATD=0XFF; //Activamos el PIN RASPIENABLE
	}
	LATD=0X00;
	Raspi_spi = SSPBUF; //Recuperamos el dato recibido´

	//           TEMPERATURA          //
	SSPBUF = response3_1; //Cargamos el primer byte
	Nop();
	while(!SSPSTATbits.BF){  //Esperamos a que lo recojan
		LATD = 0XFF;  //Activamos el PIN RASPIENABLE
	}
	LATD = 0X00;
	Raspi_spi = SSPBUF; //Recuperamos el dato recibido

	SSPBUF = response3_2; //Cargamos el segundo byte
	Nop();
	while(!SSPSTATbits.BF){ //Esperamos a que lo recojan
		LATD=0XFF; //Activamos el PIN RASPIENABLE
	}
	LATD=0X00;
	Raspi_spi = SSPBUF; //Recuperamos el dato recibido

	SSPBUF = response3_3; //Cargamos el tercer byte
	Nop();
	while(!SSPSTATbits.BF){ //Esperamos a que lo recojan
		LATD=0XFF; //Activamos el PIN RASPIENABLE
	}
	LATD=0X00;
	Raspi_spi = SSPBUF; //Recuperamos el dato recibido

	SSPBUF = response3_4;	//Cargamos el cuarto byte
 	Nop();
	while(!SSPSTATbits.BF){ //Esperamos a que lo recojan
		LATD=0XFF; //Activamos el PIN RASPIENABLE
	}
	LATD=0X00;
	Raspi_spi = SSPBUF; //Recuperamos el dato recibido

	// 				CONFIRMACION			 //
	SSPBUF = 0xAA;	//Cargamos el byte de confirmacion
 	Nop();
	while(!SSPSTATbits.BF){ //Esperamos a que lo recojan
		LATD=0XFF; //Activamos el PIN RASPIENABLE
	}
	LATD=0X00;
	Raspi_spi = SSPBUF; //Recuperamos el dato recibido

	if (Raspi_spi == 0x10){  //Activamos el actuador si asi nos lo han pedido
		LATGbits.LATG0=1;
	} 
	if (Raspi_spi == 0x20){  //Desactivamos el actuador si asi nos lo han pedido
		LATGbits.LATG0=0;
	} 
	//Terminamos por ahora
	CloseSPI();
	}
}

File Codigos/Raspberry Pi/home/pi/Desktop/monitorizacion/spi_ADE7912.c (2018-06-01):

//Ruben Garcia Segovia - 15/05/2018
#include <stdio.h>
#include <stdlib.h>
#include <string.h>
#include <errno.h>
#include <stdint.h>
#include <wiringPiSPI.h>
#include <wiringPi.h>
#include <time.h>


int main (void) {
	FILE *log;
	time_t t = time(NULL);
	struct tm tm = *localtime(&t); 
	log=fopen("../basededatos/log.txt","a"); //Guardamos el inicio del servidor 
	fprintf(log,"\n%d-%d-%d %d:%d:%d - Inicio del servidor",tm.tm_year + 1900, tm.tm_mon + 1, tm.tm_mday, tm.tm_hour, tm.tm_min, tm.tm_sec);
	fclose(log);
	while(1){ //Bucle infinito
	FILE *fp;  //Nos preparamos para abrir todos los archivos necesarios
	FILE *fp2;
	FILE *fp3;
	FILE *fp4;
	FILE *fp5;
	FILE *fp6;
	FILE *fp7;
	FILE *fp8;
	FILE *actuador;
	fp=fopen("voltaje1temporal.txt","w");  //Los archivos RAW los guardamos siempre en archivos temporales
	fp2=fopen("voltaje2temporal.txt","w");
	fp3=fopen("voltaje3temporal.txt","w");
	fp4=fopen("voltajentemporal.txt","w");
	fp5=fopen("intensidad1temporal.txt","w");
	fp6=fopen("intensidad2temporal.txt","w");
	fp7=fopen("intensidad3temporal.txt","w");
	fp8=fopen("temperaturatemporal.txt","w");
	fprintf(fp, "Ruben Garcia Segovia - VoltajeL1");
	fprintf(fp2, "Ruben Garcia Segovia - VoltajeL2");
	fprintf(fp3, "Ruben Garcia Segovia - VoltajeL3");
	fprintf(fp4, "Ruben Garcia Segovia - VoltajeLN");
	fprintf(fp5, "Ruben Garcia Segovia - IntensidadL1");
	fprintf(fp6, "Ruben Garcia Segovia - IntensidadL2");
	fprintf(fp7, "Ruben Garcia Segovia - IntensidadL3");
	fprintf(fp8, "Ruben Garcia Segovia - Temperatura");
	printf("Pruebas de SPI_Ruben_Garcia_Segovia\n");
	
	double BILLION= 1000000000; 
	int actuador_memory = 0;
	struct timespec time_origen, time_actual;
	double accum=0;
	float huecoV=0;
	float huecoI=0;
	int huecoVestado=0;
	int huecoIestado=0;
	int num_adc = 0;
	char caractuador[10];
	wiringPiSetup () ;
	pinMode (1, INPUT); 
	
	if(wiringPiSPISetup(0, 1000000) < 0) //Iniciamos el SPI 500Khz, SPI0 como CS
	{
		fprintf(stderr, "Error al leer el SPI: %s",strerror (errno));
		exit(1);
	}
	unsigned char ByteSPI[15]; //Variable para transmitir y recibir datos por spi
	long voltaje,intensidad;
	float voltajefinal,intensidadfinal;
	double notacion[4],notacion2[4];
	delay(1000); //1 segundo para dar tiempo a que se establezca el chip SPI
	//Cargamos los datos
	clock_gettime(CLOCK_MONOTONIC, &time_origen); //El reloj monotonic da siempre un valor positivo
	//e incremental en el tiempo, se utiliza para saber el tiempo que ha tardado en ejecutar 'x' lineas de codigo.
	//Lo ejecutamos aqui para tomar el primer valor
while(accum<=60){ //accum son los segundos transcurridos desde el anterior clock_gettime. Este bucle se realiza una vez por segundo
	actuador=fopen("actuador.txt","r");
	fgets(caractuador, 10, actuador); //Leemos el estado del actuador
	fclose(actuador);
	while(digitalRead(1)==LOW); //Esperamos a que el pic nos de la orden de comunicar
	//Voltaje //
	wiringPiSPIDataRW (0, ByteSPI, 1);  //Primer Byte
	ByteSPI[1] = ByteSPI[0];
	while(digitalRead(1)==LOW);
	wiringPiSPIDataRW (0, ByteSPI, 1);  //Segundo Byte
	ByteSPI[2] = ByteSPI[0];
	while(digitalRead(1)==LOW);
	wiringPiSPIDataRW (0, ByteSPI, 1);  //Tercer Byte
	ByteSPI[3] = ByteSPI[0];
	while(digitalRead(1)==LOW);
	wiringPiSPIDataRW (0, ByteSPI, 1);  //Cuarto Byte
	ByteSPI[4] = ByteSPI[0];
		//Intensidad //
	wiringPiSPIDataRW (0, ByteSPI, 1);  //Primer Byte
	ByteSPI[5] = ByteSPI[0];
	while(digitalRead(1)==LOW);
	wiringPiSPIDataRW (0, ByteSPI, 1);  //Segundo Byte
	ByteSPI[6] = ByteSPI[0];
	while(digitalRead(1)==LOW);
	wiringPiSPIDataRW (0, ByteSPI, 1);  //Tercer Byte
	ByteSPI[7] = ByteSPI[0];
	while(digitalRead(1)==LOW);
	wiringPiSPIDataRW (0, ByteSPI, 1);  //Cuarto Byte
	ByteSPI[8] = ByteSPI[0];
		//Temperatura //
	wiringPiSPIDataRW (0, ByteSPI, 1);  //Primer Byte
	ByteSPI[9] = ByteSPI[0];
	while(digitalRead(1)==LOW);
	wiringPiSPIDataRW (0, ByteSPI, 1);  //Segundo Byte
	ByteSPI[10] = ByteSPI[0];
	while(digitalRead(1)==LOW);
	wiringPiSPIDataRW (0, ByteSPI, 1);  //Tercer Byte
	ByteSPI[11] = ByteSPI[0];
	while(digitalRead(1)==LOW);
	wiringPiSPIDataRW (0, ByteSPI, 1);  //Cuarto Byte
	ByteSPI[12] = ByteSPI[0];
	if (caractuador[0] == '1'){ //Si el actuador esta activado...
		ByteSPI[0] = 0x10; //Se manda un 0x10 al pic (activar actuador)
		if(actuador_memory==0){ //Si no estaba activado de antes...
			FILE *log;
			time_t t = time(NULL);
			struct tm tm = *localtime(&t);
			log=fopen("../basededatos/log.txt","a"); //Se apunta en el log
			fprintf(log,"\n%d-%d-%d %d:%d:%d - Encendido del actuador",tm.tm_year + 1900, tm.tm_mon + 1, tm.tm_mday, tm.tm_hour, tm.tm_min, tm.tm_sec);
			fclose(log);
		}
		actuador_memory = 1;
	} else if(caractuador[0] == '0' && actuador_memory == 1){  //Si no esta activado y antes si lo estaba
		ByteSPI[0]= 0x20; //Se manda 0x20 al pic (Desactivar actuador)
		FILE *log;
		time_t t = time(NULL);
		struct tm tm = *localtime(&t);
		log=fopen("../basededatos/log.txt","a");//Se apunta en el log
		fprintf(log,"\n%d-%d-%d %d:%d:%d - Apagado del actuador",tm.tm_year + 1900, tm.tm_mon + 1, tm.tm_mday, tm.tm_hour, tm.tm_min, tm.tm_sec);
		fclose(log);
		actuador_memory = 0;
	} else {
		ByteSPI[0]= 0x20; //Se manda el 0x20
	}
	while(digitalRead(1)==LOW); //Nos esperamos a que el pic nos de permite de comunicacion
	wiringPiSPIDataRW (0, ByteSPI, 1);  //Byte de confirmacion y envio de actuador
	
	//Calculo del voltaje
	voltaje = ByteSPI[1] * 1024;
	voltaje += ByteSPI[2] * 512;
	voltaje += ByteSPI[3] * 256;
	voltaje = voltaje + ByteSPI[4];
	voltajefinal = (voltaje*4.096)/4096;
	notacion[num_adc] = (voltajefinal * 100);
	
	//Calculo de la intensidad
	intensidad = ByteSPI[5] * 1024;
	intensidad += ByteSPI[6] * 512;
	intensidad += ByteSPI[7] * 256;
	intensidad = intensidad + ByteSPI[8];
	voltajefinal = (intensidad*4.096)/4096;
	notacion2[num_adc] = (intensidadfinal * 100);
	
	//Calculo de la temperatura
	temperatura = ByteSPI[5] * 1024;
	temperatura += ByteSPI[6] * 512;
	temperatura += ByteSPI[7] * 256;
	temperatura = temperatura + ByteSPI[8];  //Sustituir valores por los del ADC
	temperaturafinal[num_adc] = ganancia[num_adc]*temperatura + 8.72101*TEMPOS[num_adc]*(2^11)*10^(-5) - 306.47
	
	//Detectamos posibles cortes
	if(huecoV>3000 && huecoVestado==0){
		huecoVestado=1;
	}
	if(huecoI>3000 && huecoIestado==0){
		huecoIestado=1;
	} //Tres mil muestras es aproximadamente 1 segundo
	if(huecoVestado==1 && huecoV >3000){
		FILE *log;
		time_t t = time(NULL);
		struct tm tm = *localtime(&t);
		log=fopen("../basededatos/log.txt","a"); //Escribimos en el log el corte
		fprintf(log,"\n%d-%d-%d %d:%d:%d - Corte en el Voltaje",tm.tm_year + 1900, tm.tm_mon + 1, tm.tm_mday, tm.tm_hour, tm.tm_min, tm.tm_sec);
		fclose(log);
		log=fopen("../monitorizacion/estado.txt","w");
		fprintf(log,"1");
		fclose(log);
		huecoVestado = 2;
	}
	if(huecoVestado==2 && huecoV ==0){
		FILE *log;
		time_t t = time(NULL);
		struct tm tm = *localtime(&t);
		log=fopen("../basededatos/log.txt","a"); //Escribimos en el log la reanudacion
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
